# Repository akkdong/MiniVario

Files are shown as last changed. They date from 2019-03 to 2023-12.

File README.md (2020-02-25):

# MiniVario
ESP32+BARO+GPS+E-INK

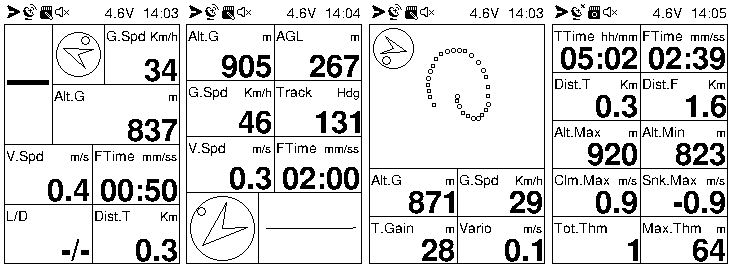
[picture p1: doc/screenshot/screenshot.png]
Device Screenshots


<br>
<br>
<center>
  <p>
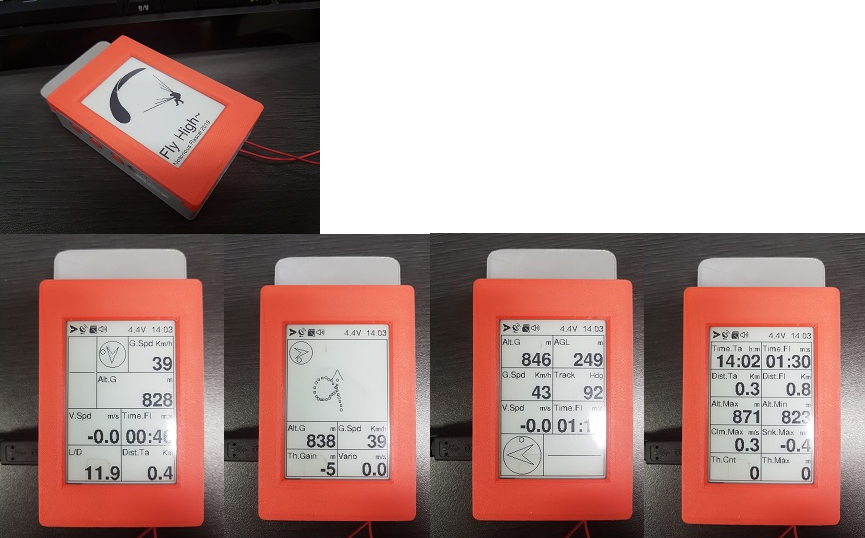
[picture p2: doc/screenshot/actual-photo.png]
    
  </p>
  <p>
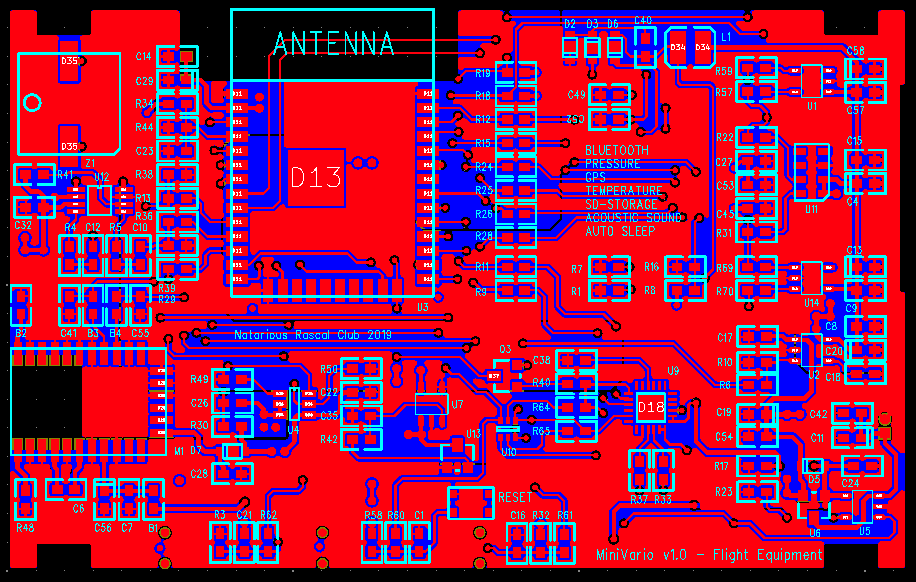
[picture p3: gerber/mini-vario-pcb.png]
    
  </p>
</center>

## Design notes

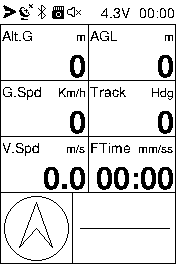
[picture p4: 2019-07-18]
doc/screenshot/screen02.bmp

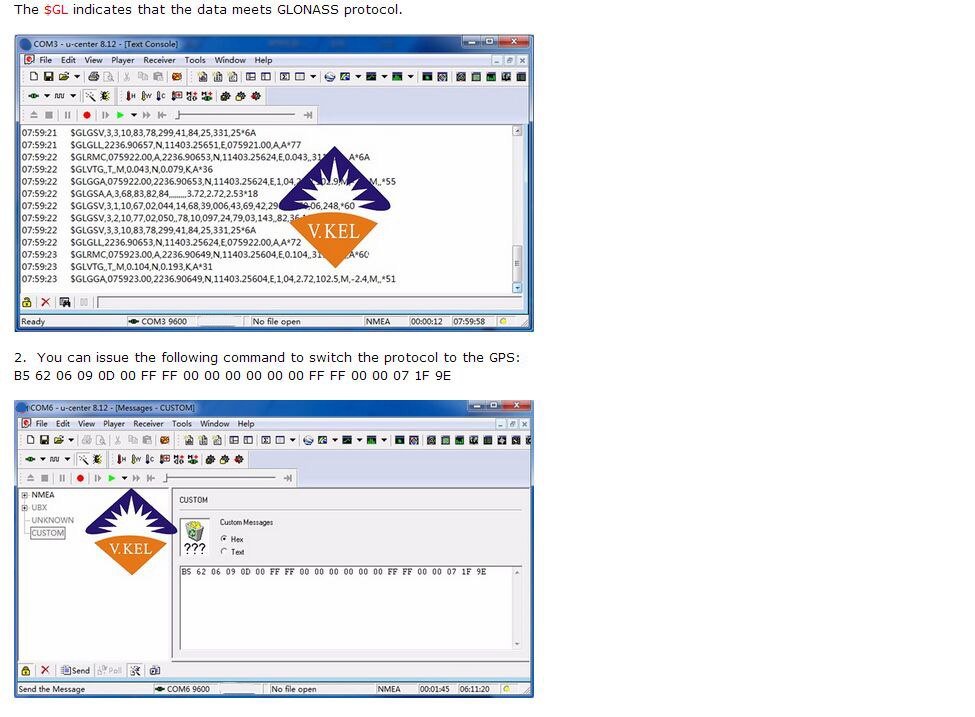
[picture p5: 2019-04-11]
doc/gps-alternate/6 GPS and GLONASS Switching.jpg

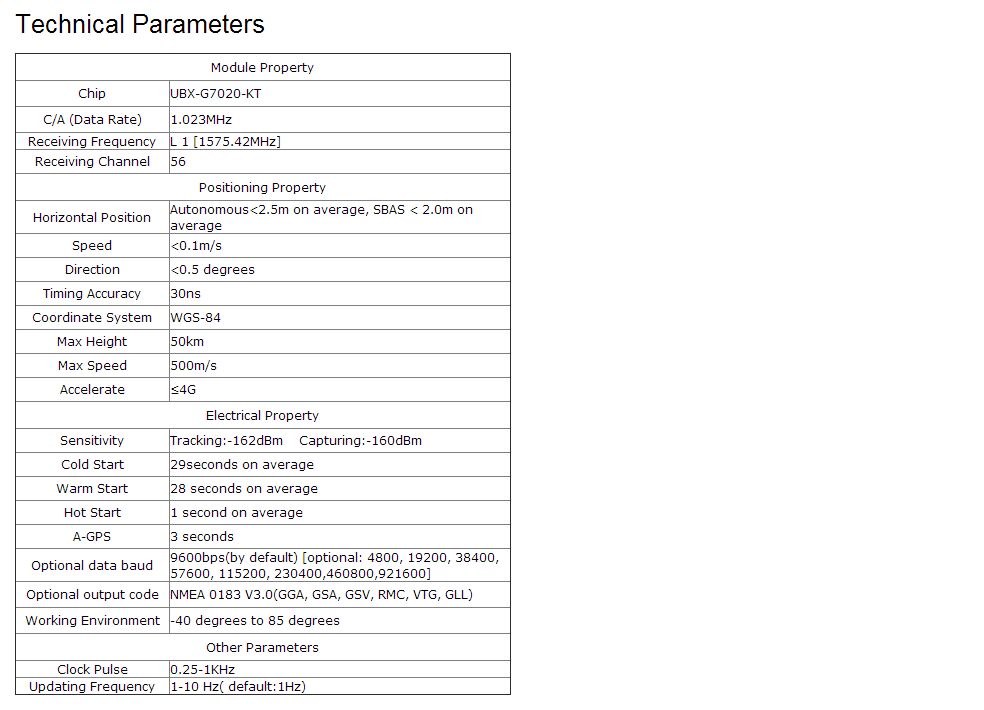
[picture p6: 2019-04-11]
doc/gps-alternate/1 Technical Parameters.jpg

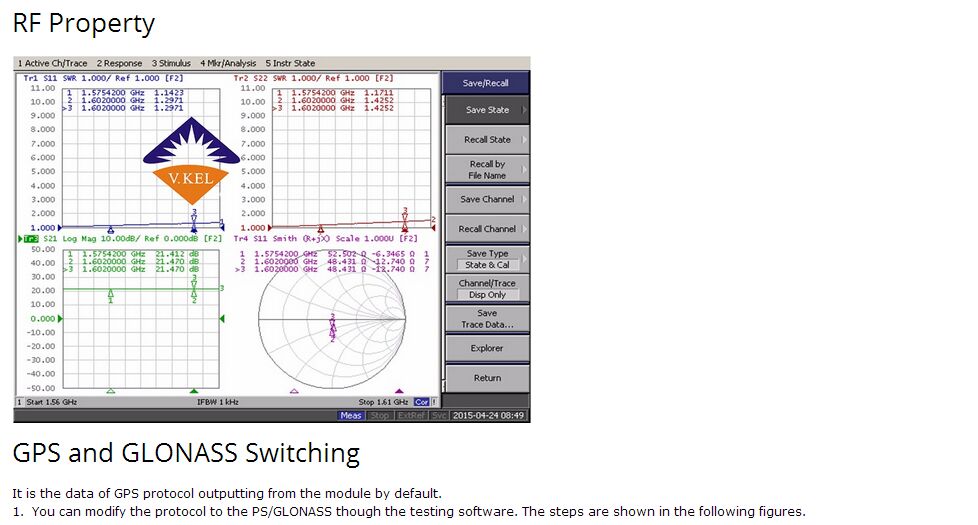
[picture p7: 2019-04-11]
doc/gps-alternate/4 RF Property.jpg

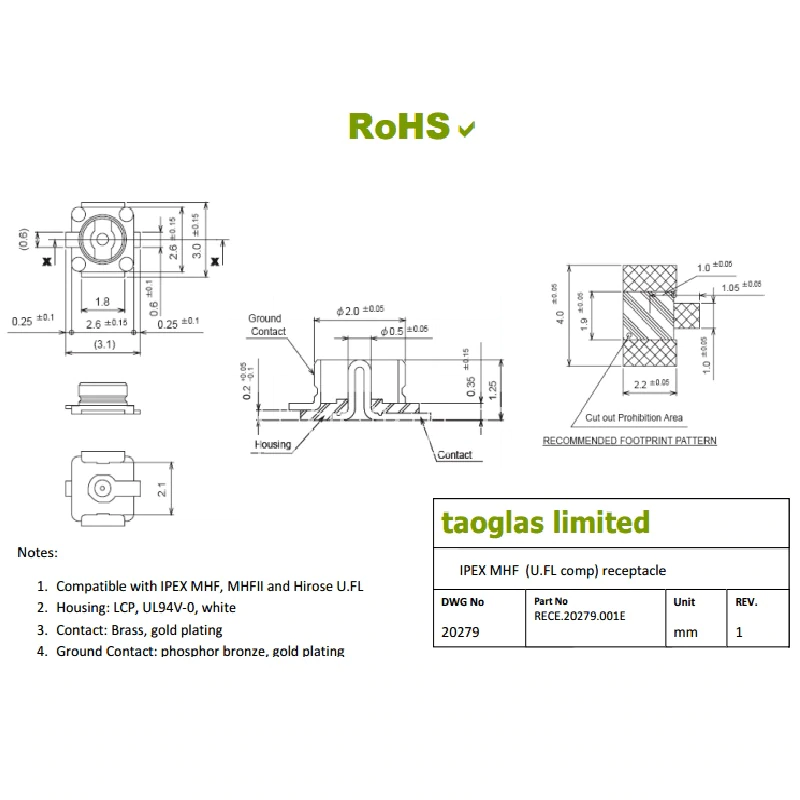
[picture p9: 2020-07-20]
doc/IPEX-IPX-connetor.webp

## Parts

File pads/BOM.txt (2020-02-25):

Item	Qty	Reference	Part Name	Manufacturer	Description
1	1	U14	24CW128X		
2	1	U6	AO3401A		
3	1	Q3	BC817-16LT1	MOTOROLA	GENERAL PURPOSE NPN SILICON TRANSISTOR
4	2	L4-5	BEAD		
5	1	B2	BEAD-0603(1608),1.8nH		
6	2	B3-4	BEAD-0603(1608),47nH		
7	1	B1	BEAD-0603(1608),ferrite 1K, 1MHz		
8	1	Z1	BUZZER		
9	1	C23	C-N-0603(1608),0.01uF		
10	16	C1-3 C7-9 C14-15 C21 C25 C27 C37 C40 C42 C54 C57	C-N-0603(1608),0.1uF		
11	1	C16	C-N-0603(1608),0.1uF(NC)		
12	1	C26	C-N-0603(1608),1000pF		
13	18	C10 C12 C17 C22 C28 C32-33 C35 C43-52	C-N-0603(1608),1uF		
14	2	C31 C39	C-N-0603(1608),220pF		
15	3	C6 C41 C55	C-N-0603(1608),22pF		
16	1	C24	C-N-0603(1608),4.7uF		
17	1	C38	C-N-0603(1608),4.7uF (NC)		
18	1	C53	C-N-0603(1608),47uF		
19	1	C18	C-N-0603(1608),N/C		
20	1	C59	C-N-0603(1608),SHORT		
21	12	C4-5 C11 C13 C19-20 C29-30 C34 C36 C56 C58	C-P-0805(2012),10uF		
22	1	L1	COIL,???		
23	1	U9	CP2104		
24	5	D2-3 D5-7	D-1206(3216),S1M		
25	1	J3	EINK-WARESHARE		
26	1	U3	ESP-WROOM32		
27	1	U4	FDC6326L		
28	1	M1	GPS_M20050-1		
29	2	D1 D4	LED		
30	1	U13	MAX809		
31	1	U1	MCP9800		
32	1	U5	MCP73831		
33	1	J2	MICRO-SD		
34	1	U11	MS5611-01BA		
35	1	U12	PAM8304		
36	2	R8 R16	R-0603(1608),0K		
37	10	R9 R11-12 R15 R24-26 R28 R33 R37	R-0603(1608),0R		
38	5	R30 R40 R48 R64-65	R-0603(1608),100K		
39	14	R6 R21-22 R27 R29 R31 R35 R45-47 R57 R59 R69-70	R-0603(1608),100R		
40	18	R1 R3 R10 R14 R17-19 R32 R38-39 R41 R50-54 R56 R58	R-0603(1608),10K		
41	5	R2 R20 R49 R66-67	R-0603(1608),1K		
42	2	R42 R44	R-0603(1608),1M		
43	1	R23	R-0603(1608),2K		
44	1	R7	R-0603(1608),3R/0.47R		
45	3	R13 R36 R43	R-0603(1608),4.7K		
46	4	R60-63	R-0603(1608),470R		
47	2	R4-5	R-0603(1608),50K		
48	1	R34	R-0603(1608),560K		
49	1	R55	R-0603(1608),N/C		
50	1	Q1	SI1308EDL		
51	1	J5	SIP_02		
52	4	SW1 SW3-5	SW-SPST-ITS-1164		
53	1	U2	TC1017-3V3		
54	1	U7	TPS78233		
55	1	U10	UMH3N		
56	1	J1	USB_TYPEB_MINI

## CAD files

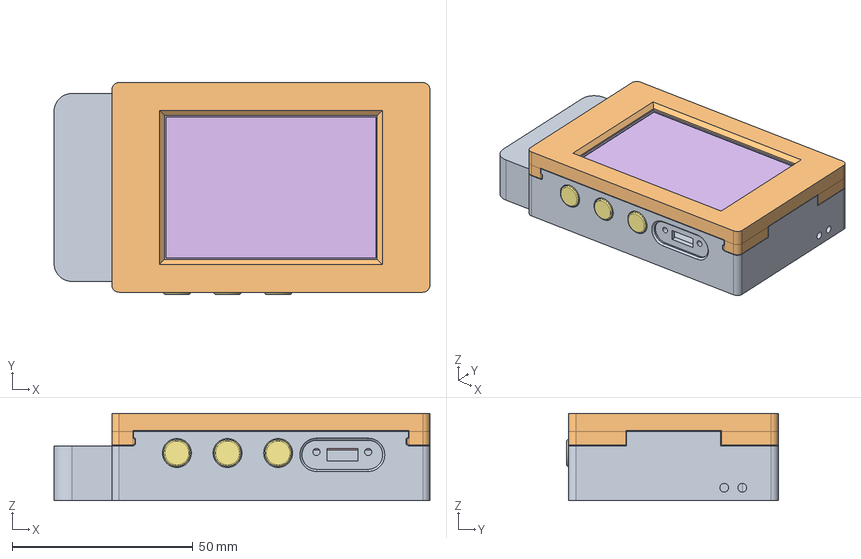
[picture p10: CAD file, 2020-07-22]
model/Case-Alt-RoundBtn.FCStd
104.0 x 58.6 x 24.2 mm
Case-Lower
Case-Cover
LCD-Holder-L
LCD-Holder-R
PCB-Body
LCD-Body
Buttons

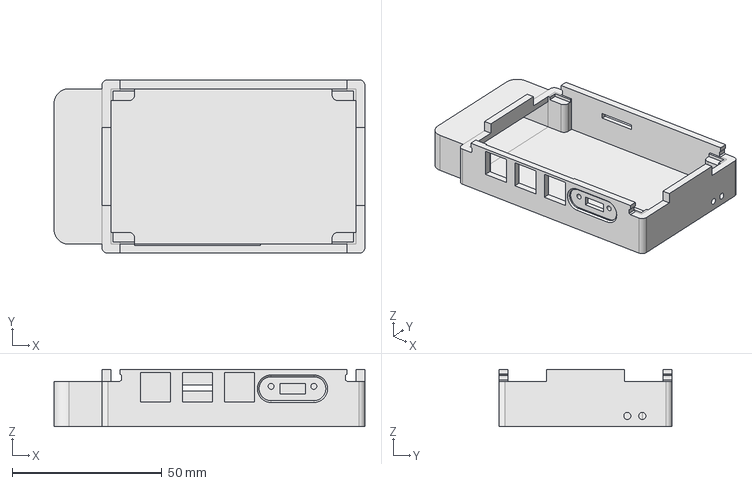
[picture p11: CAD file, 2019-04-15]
model/Case-Alt.FCStd
104.0 x 58.0 x 19.2 mm

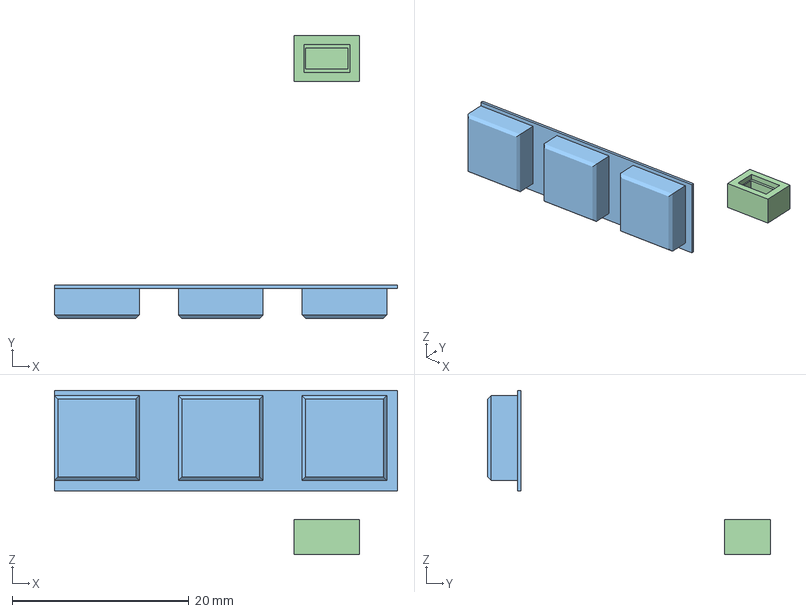
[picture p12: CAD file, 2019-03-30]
model/Case.FCStd
38.8 x 32.0 x 18.6 mm
Buttons
MS5611-Cover
Buttons (Meshed)
MS5611-Cover (Meshed)

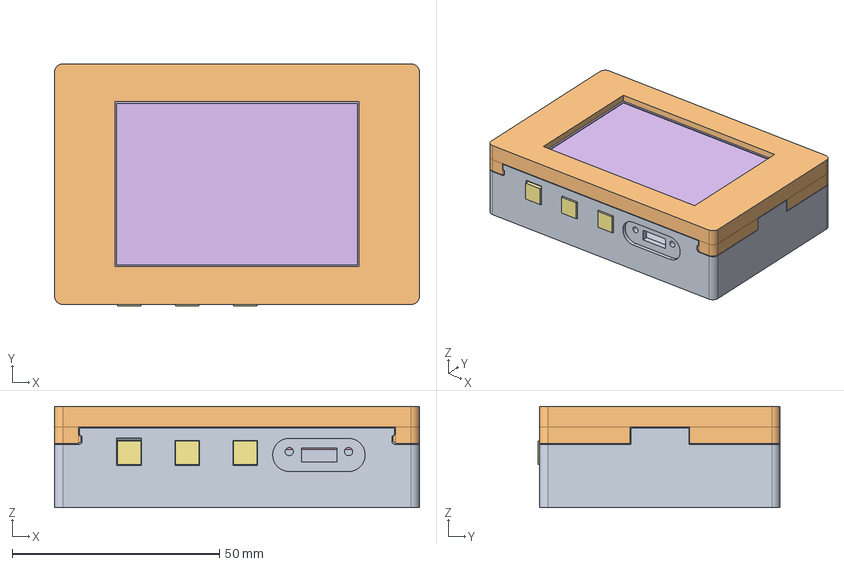
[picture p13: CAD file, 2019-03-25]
model/Case-Small Button.FCStd
88.0 x 58.4 x 24.4 mm
Case-Lower
Case-Cover
LCD-Holder-L
LCD-Holder-R
PCB-Body
LCD-Body
Buttons

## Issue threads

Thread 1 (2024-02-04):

Failed to start after welding

mspudi, 2024-02-04:
1：MiniVario_Rev2.pcb   Failed to start after welding

2：MiniVario_Rev2.pdf / MiniVario_Full.pdf  There is no difference between the two

3：src-platformio   /  Arduino IDE  master/src/    Burn test after compilation

Make sure there is no problem with the circuit

akkdong, 2024-02-22:
1. Hm...
- Actually GPS has problem but it's not affect to boot up.
- Please check one by one:  Power, USB(2serial), ...

2. Power input of GPS module is changed.
- Anyway GPS works well. but it cann't find satellite
- External ANTENA is needed. : I will show how to fix it.

3. recommend src-platformio
- use proper EPD: refer USE_GOOD_DISPLAY  macro in platformio.ini

--> There is no problem to start but some H/W fix is needed.

mspudi, 2024-10-08:
[2024-09-30 13:32:45.227]# RECV ASCII>
Start MiniVario...
[2024-09-30 13:32:45.354]# RECV ASCII>
Initializing SD card...
E (336) sdmmc_io: sdmmc_io_reset: unexpected return: 0x108
E (337) vfs_fat_sdmmc: sdmmc_card_init failed (0x108).
[   358][E][SD_MMC.cpp:148] begin(): Failed to initialize the card (0x108). Make sure SD card lines have pull-up resistors in place.
SD Card Mount Failed
Failed to initialize SD Card.

[2024-09-30 13:32:45.650]# RECV ASCII>
DeviceDefault.enableBT = 0
DeviceDefault.enableSound = 0
DeviceDefault.enableSimulation = 0
DeviceDefault.enableNmeaLogging = 0
DeviceDefault.btName = MiniVario
DeviceDefault.wifiSSID = MiniVario
DeviceDefault.wifiPassword = 123456789
VolumeSettings.vario = 0
VolumeSettings.effect = 100
VolumeSettings.autoTurnOn = 1
VarioSettings.sinkThreshold = -3.000000
VarioSettings.climbThreshold = 0.200000
VarioSettings.sensitivity = 0.120000
VarioSettings.sentence = 2
VarioSettings.altitudeRef1 = 0.000000
VarioSetting

[2024-09-30 13:32:45.742]# RECV ASCII>
s.altitudeRef2 = 0.000000
VarioSettings.altitudeRef3 = 0.000000
VarioSettings.dampingFactor = 0.050000
KalmanParameter.varZMeas = 400.000000
KalmanParameter.varZAccel = 50000.000000
KalmanParameter.varAccelBias = 1.000000
GliderInfo.type = 1
GliderInfo.manufacture = Ozone
GliderInfo.model = Zeno
IGCLogger.enable = 1
IGCLogger.takeoffSpeed = 6
IGCLogger.landingSpeed = 2
IGCLogger.landingTimeout = 10000
IGCLogger.loggingInterval = 1000
IGCLogger.pilot = akkdong
IGCLogger.timezone = 9.000000

[2024-09-30 13:32:46.784]# RECV ASCII>
E (3978) task_wdt: Task watchdog got triggered. The following tasks did not reset the watchdog in time:
E (3978) task_wdt:  - loopTask (CPU 1)
E (3978) task_wdt: Tasks currently running:
E (3978) task_wdt: CPU 0: IDLE0
E (3978) task_wdt: CPU 1: IDLE1
E (3978) task_wdt: Aborting.

abort() was called at PC 0x400f5160 on core 0
Backtrace: 0x40083fe1:0x3ffbf17c |<-CORRUPTED
ELF file SHA256: 9320ff9e2883cf93
[2024-09-30 13:32:47.000]# RECV ASCII>
Rebooting...

mspudi, 2024-10-08:
I use an external module for GPS, as long as it can decode NMEA, that's enough。The system keeps restarting after power on, please modify it       void resetDevice()
{
	//
	display.showPopup(NULL);

	//
	btMan.stopLogging();
	btMan.end();

	// close logging-file
	logger.end(nmeaParser.getDateTime());

	// turn-off peripherals
	setPinState(&powerPins[0], PIN_STATE_INACTIVE);
	setPinState(&powerPins[1], PIN_STATE_INACTIVE);
	delay(1000); // delay will trigger Task watchdog!

	// or manually reset
	ESP.restart();
}

akkdong, 2024-10-13:
The current problem is caused by watchdog timeout. The watchdog count should be reset periodically. The watchdog resets itself periodically in the main loop and in the kalman-vario task. For some reason, the loop does not seem to work properly. You may be able to determine why the loop stops working by disabling the watchdog. Try commenting out all lines starting with "TaskWatchodog::" in main.cpp and KalmanVario.cpp, or changing the value of the TASK_TIMEOUT_S macro to a larger value. TASK_TIMEOUT_S is the watchdog timeout period, which is currently set to 1 second.

mspudi, 2024-10-17:
I'm ready to use it https://github.com/moononournation/Arduino_GFX Can you explain the logic and method of replacing EPaper with ILI9341? Thank you. Currently, the MiniVario motherboard has been used to test the Arduino FX examples    ILI9341   Display successful.
 platformio.ini
    adafruit/Adafruit GFX Library @ ~1.11.5
    adafruit/Adafruit BusIO@^1.16.1
    moononournation/GFX Library for Arduino@^1.4.7

mspudi, 2024-11-28:
The settings in Device Settings fail to be saved after modification.
The Firmware Update is ineffective.
The download of Track Logs is not working.
Are the above several functions not completed?

akkdong, 2024-11-30:
1. DeviceContext::load() and DeviceContext::save() unsupported
Now device-context is loaded from "config.json" file: main.cpp line 1032
Actually it is read-only. You must update "config.json" in manually
2. Firmware Update
It is not tested!!
3. Track Log download
Of cause It is working. But it's tricky to use.
Web service use WebServer class which is implemented a long time ago. However WebServer supports only on connection at a time, so its functionality is limited. There is new method which is uses Capital Portal. If you look at Cube-M3, There is something you can refer to. (https://github.com/akkdong/Cube/tree/main/M3/disp) Thre is a plan to renew MiniVario, But thre is not enough time. Sorry!

mspudi, 2024-12-12:
Thank you for your answer. The above functions have been basically fixed, but further testing is still needed. Could you please tell me why there is no sound even when the sound is turned on, whether in flight mode or normal mode?

akkdong, 2024-12-13:
There may be several reasons why there is no sound. The best way to find the cause is to upload the sound test firmware and check the signal of each stage (MCU, FILTER, AMP, SPK). You can use the src/test/SineWave firmware, but since it is a previous build environment, it seems that some additional work is needed. Also, you need to check the pin number in advance.
If everything is fine and there is no sound even when you turn on the sound in normal mode, it may not be easy to find the cause. I don't have any ideas yet on how to fix this.

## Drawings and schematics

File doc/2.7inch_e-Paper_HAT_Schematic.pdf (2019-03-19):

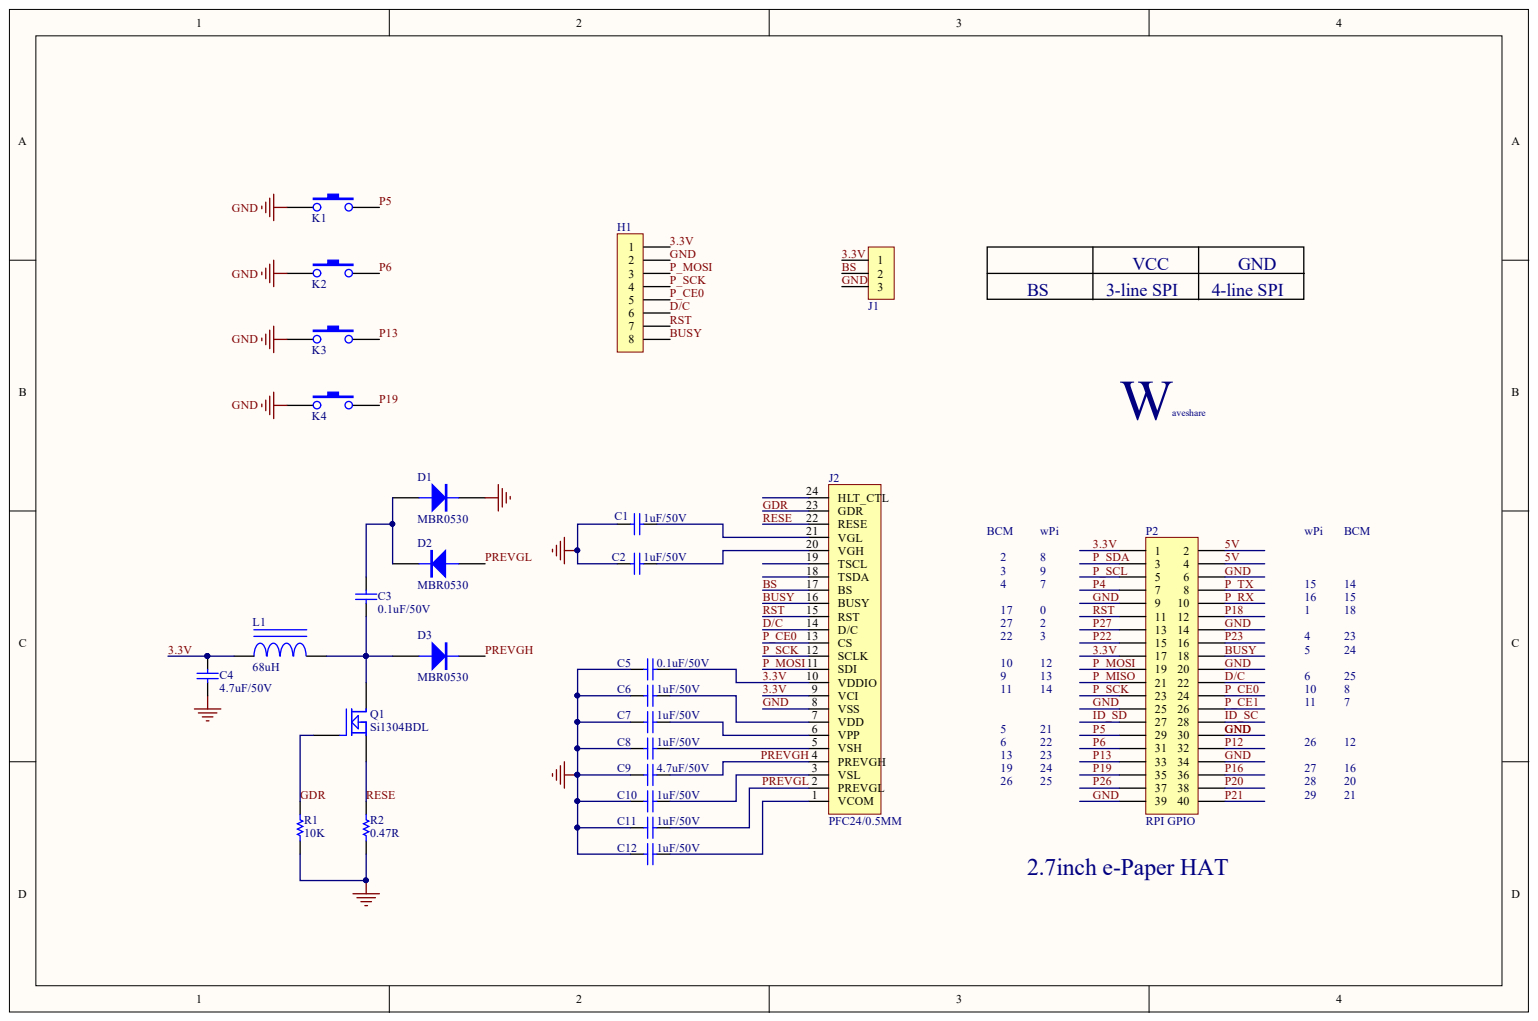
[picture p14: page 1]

PRE V G L | 2

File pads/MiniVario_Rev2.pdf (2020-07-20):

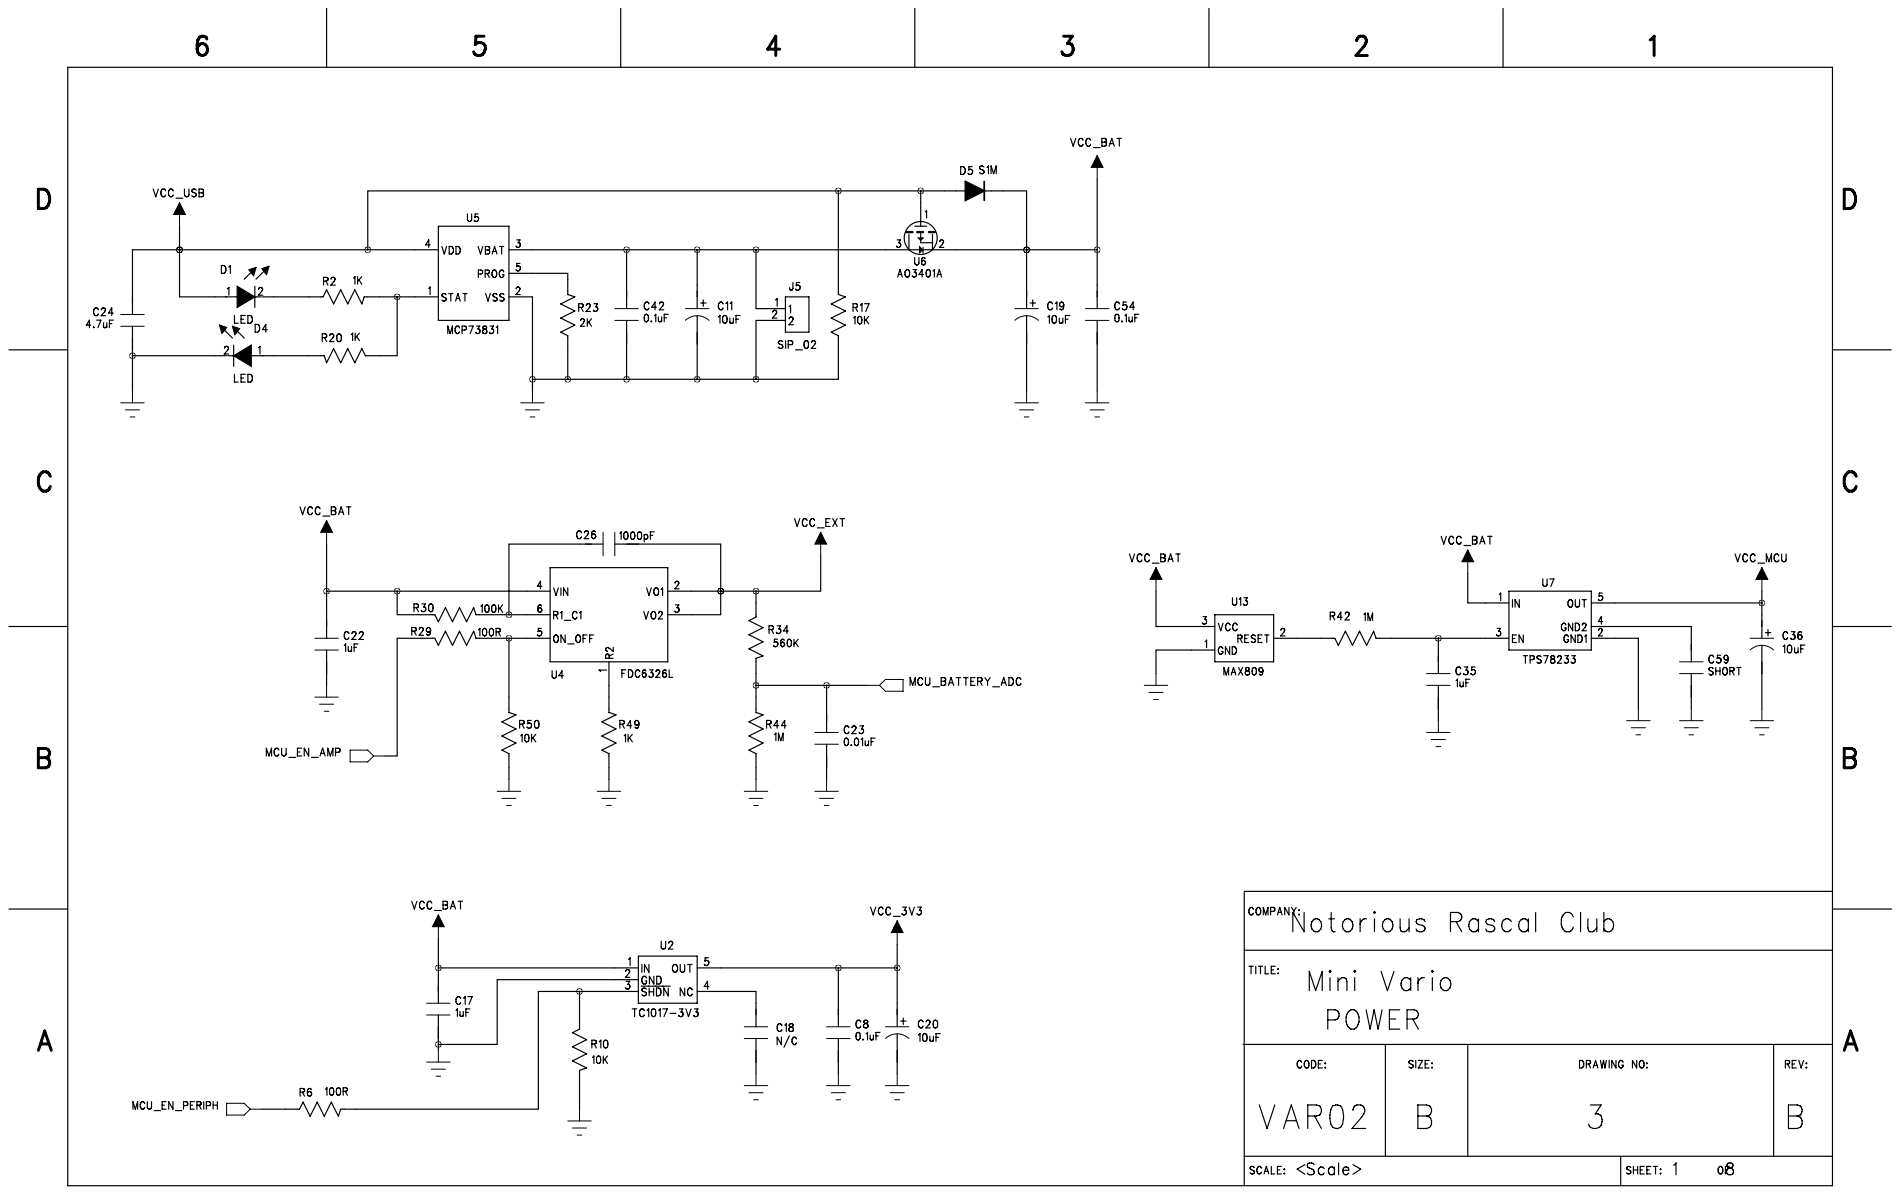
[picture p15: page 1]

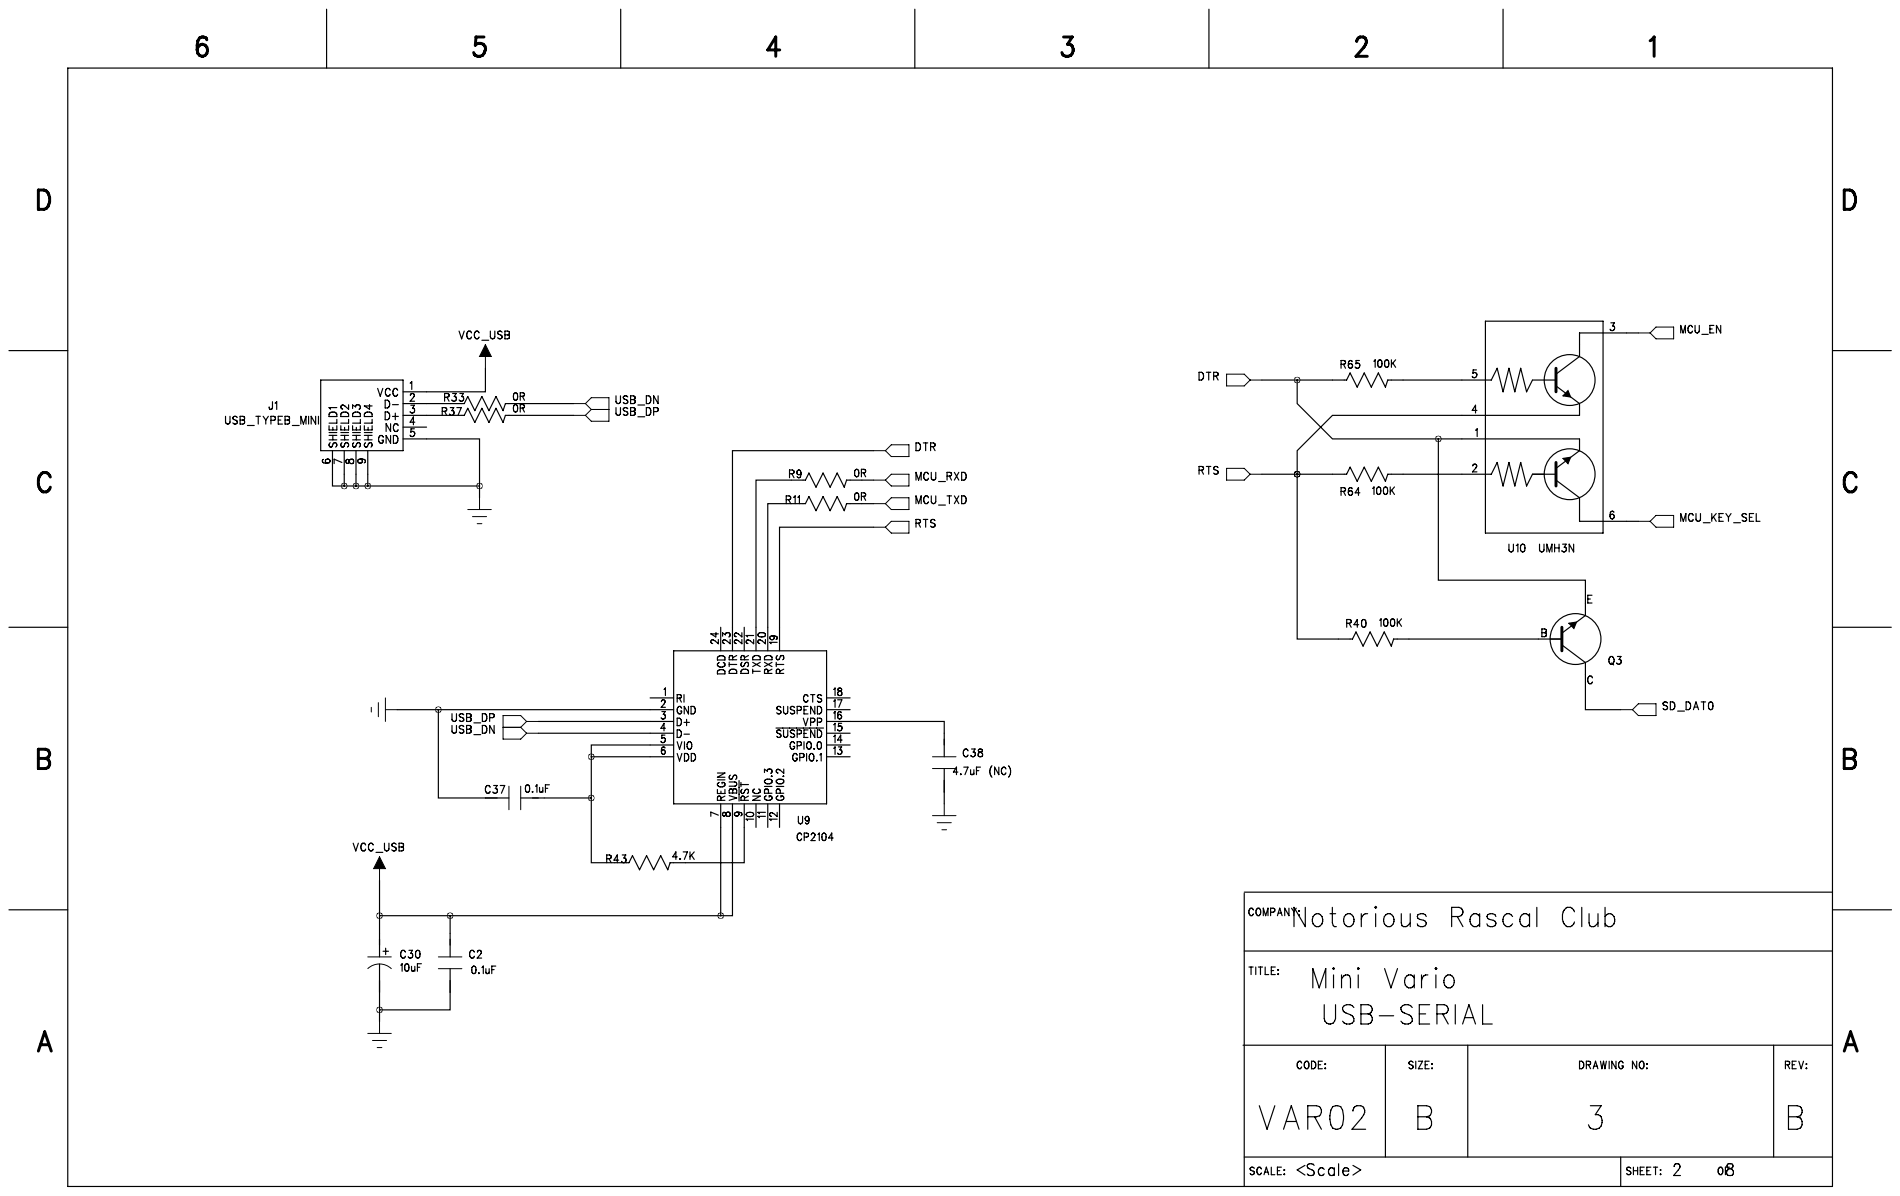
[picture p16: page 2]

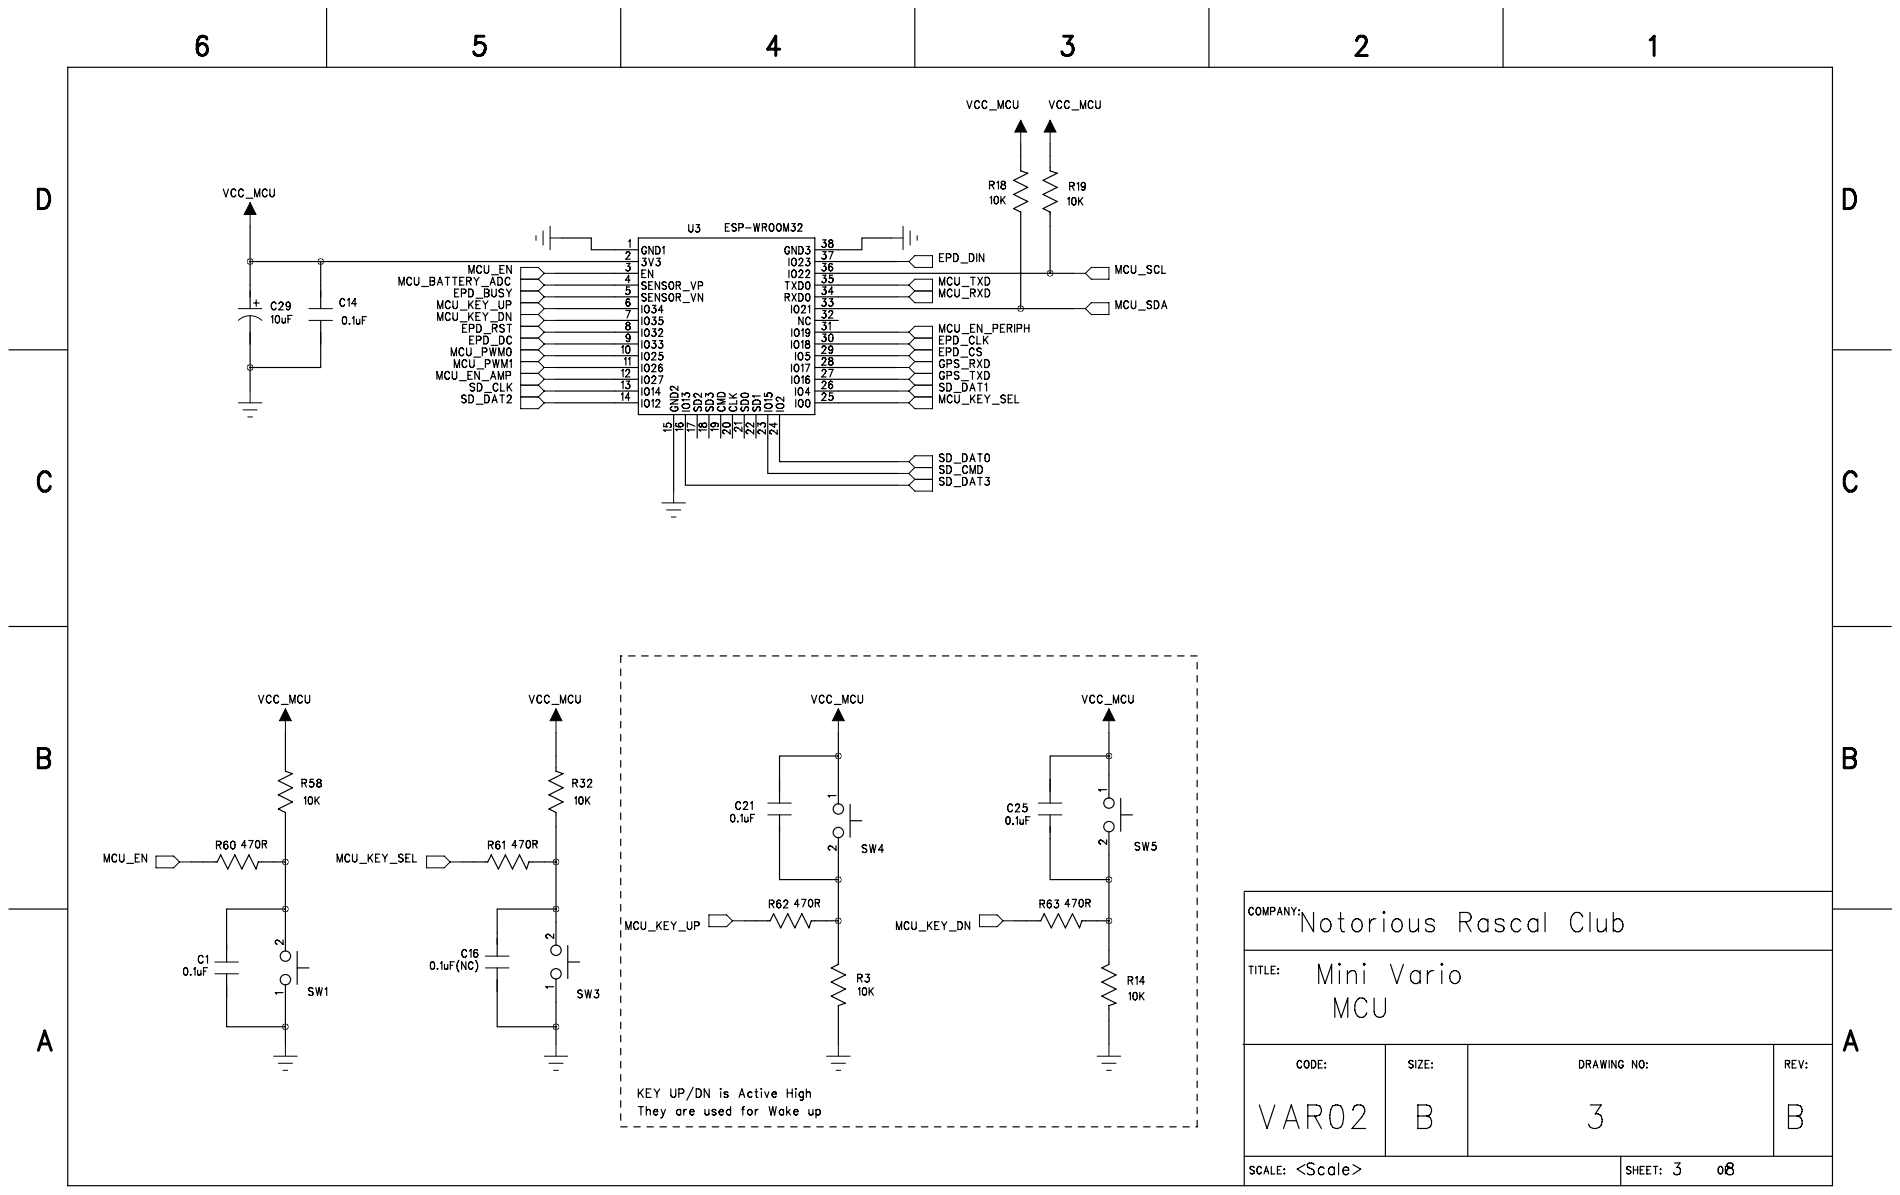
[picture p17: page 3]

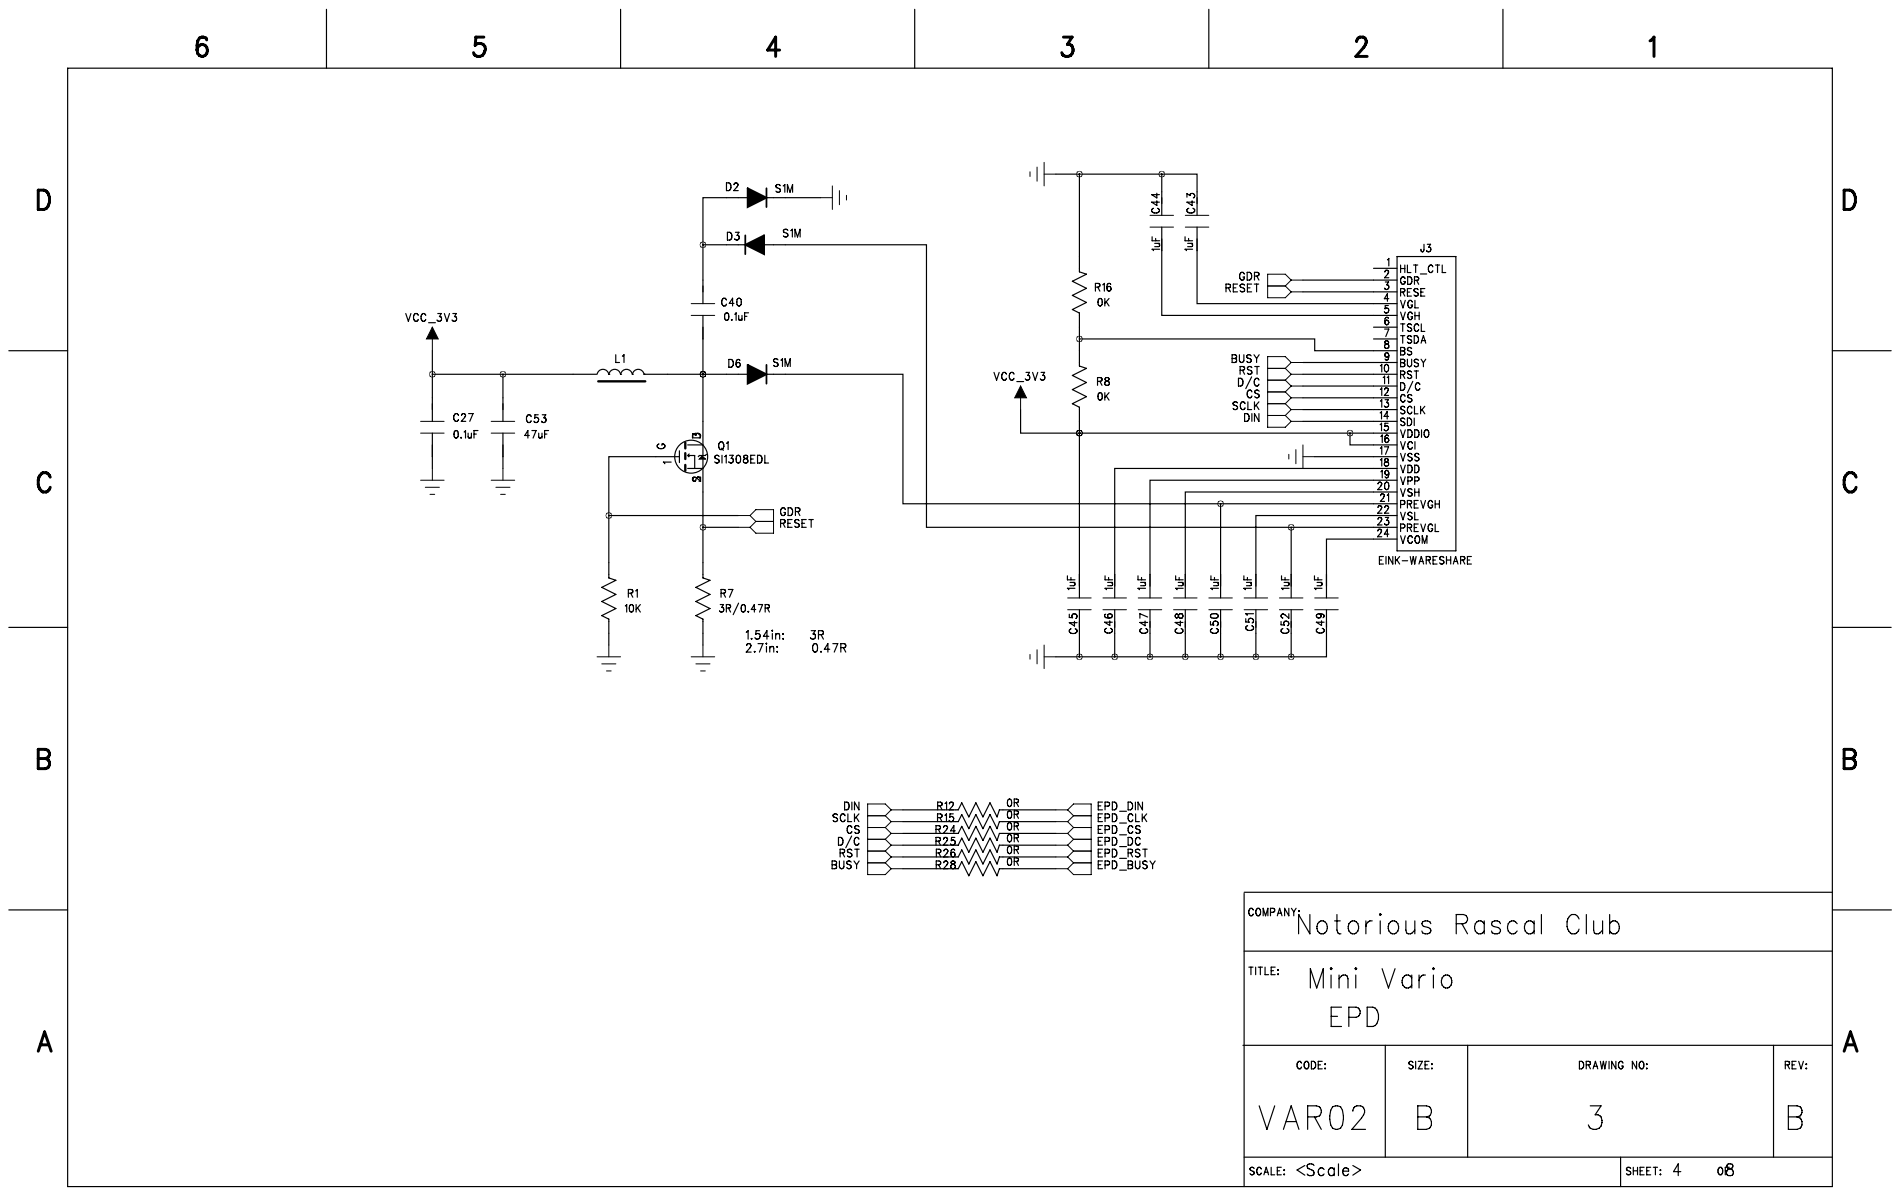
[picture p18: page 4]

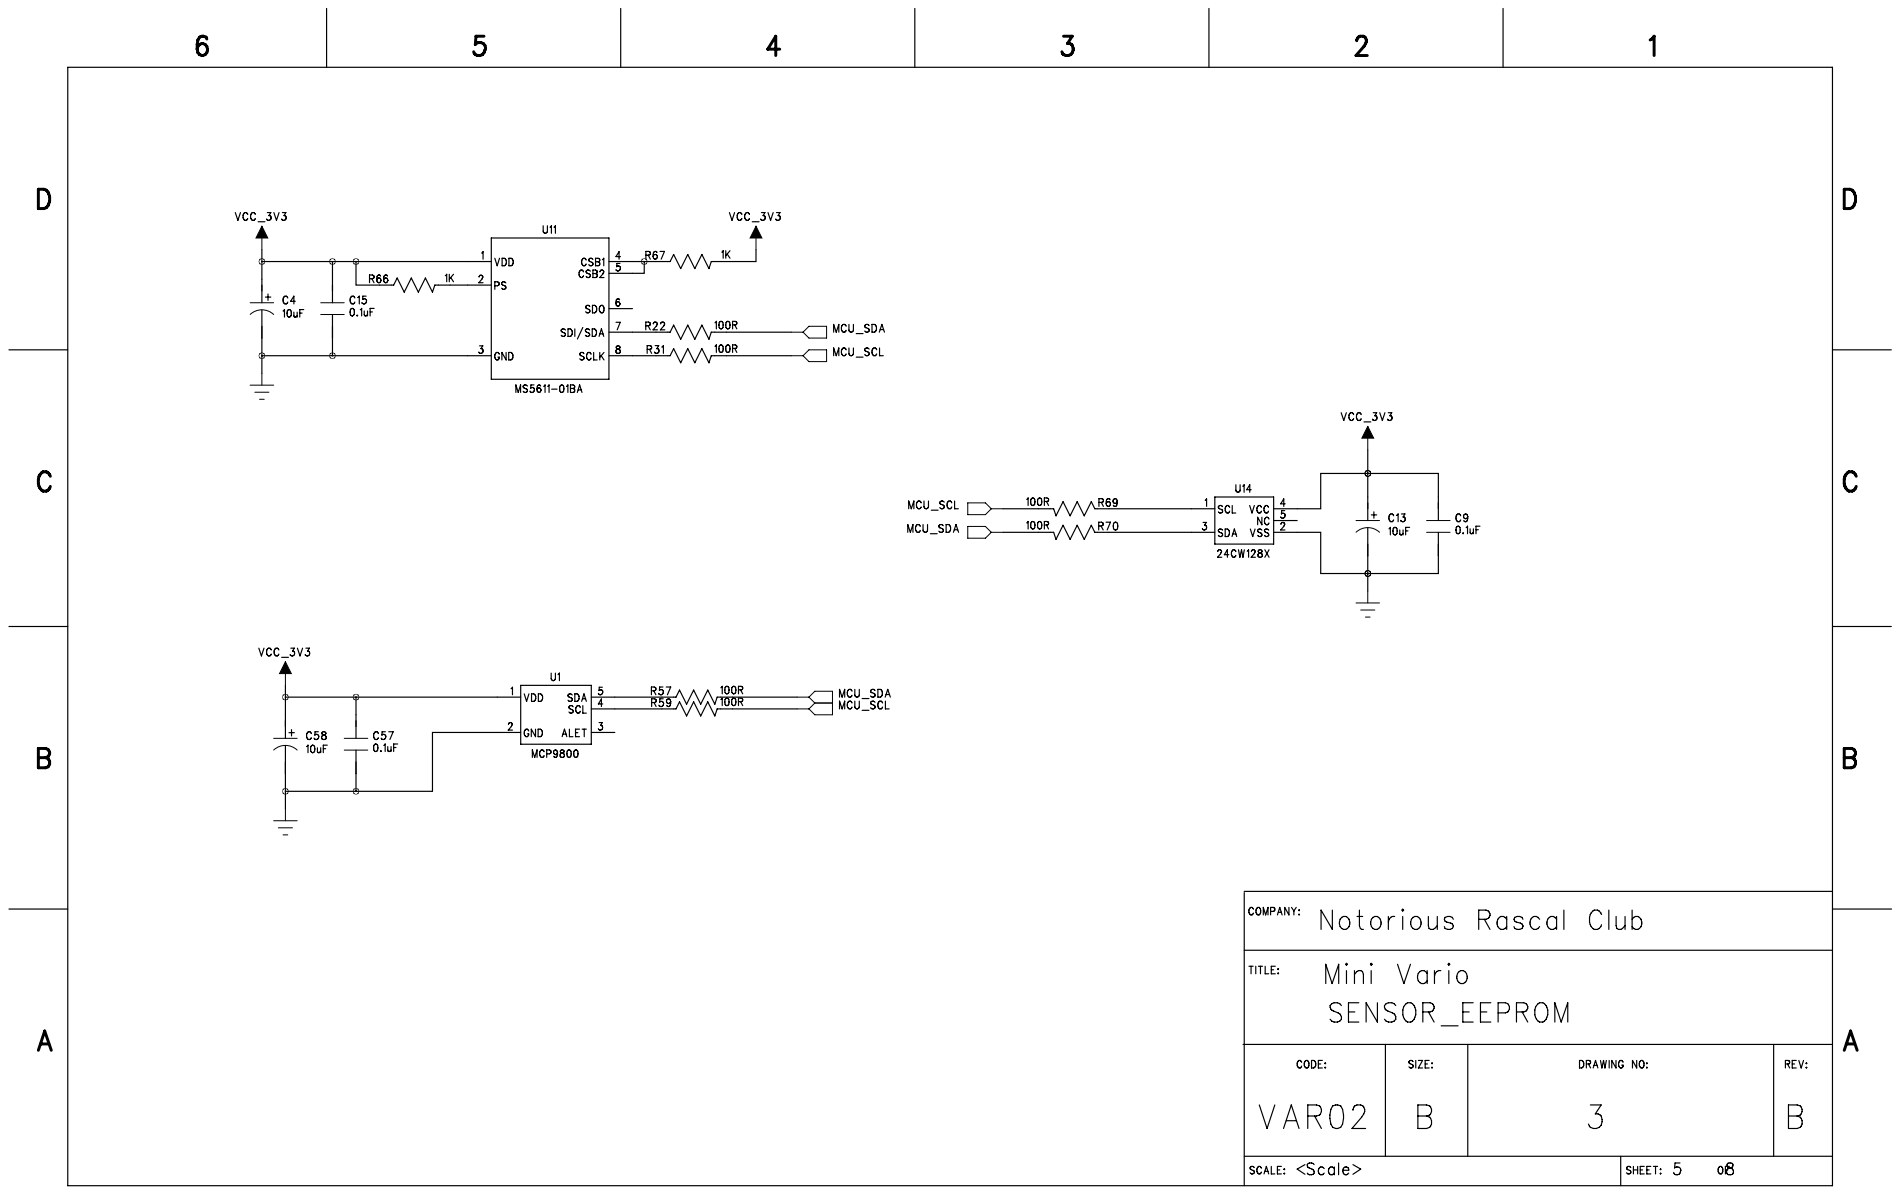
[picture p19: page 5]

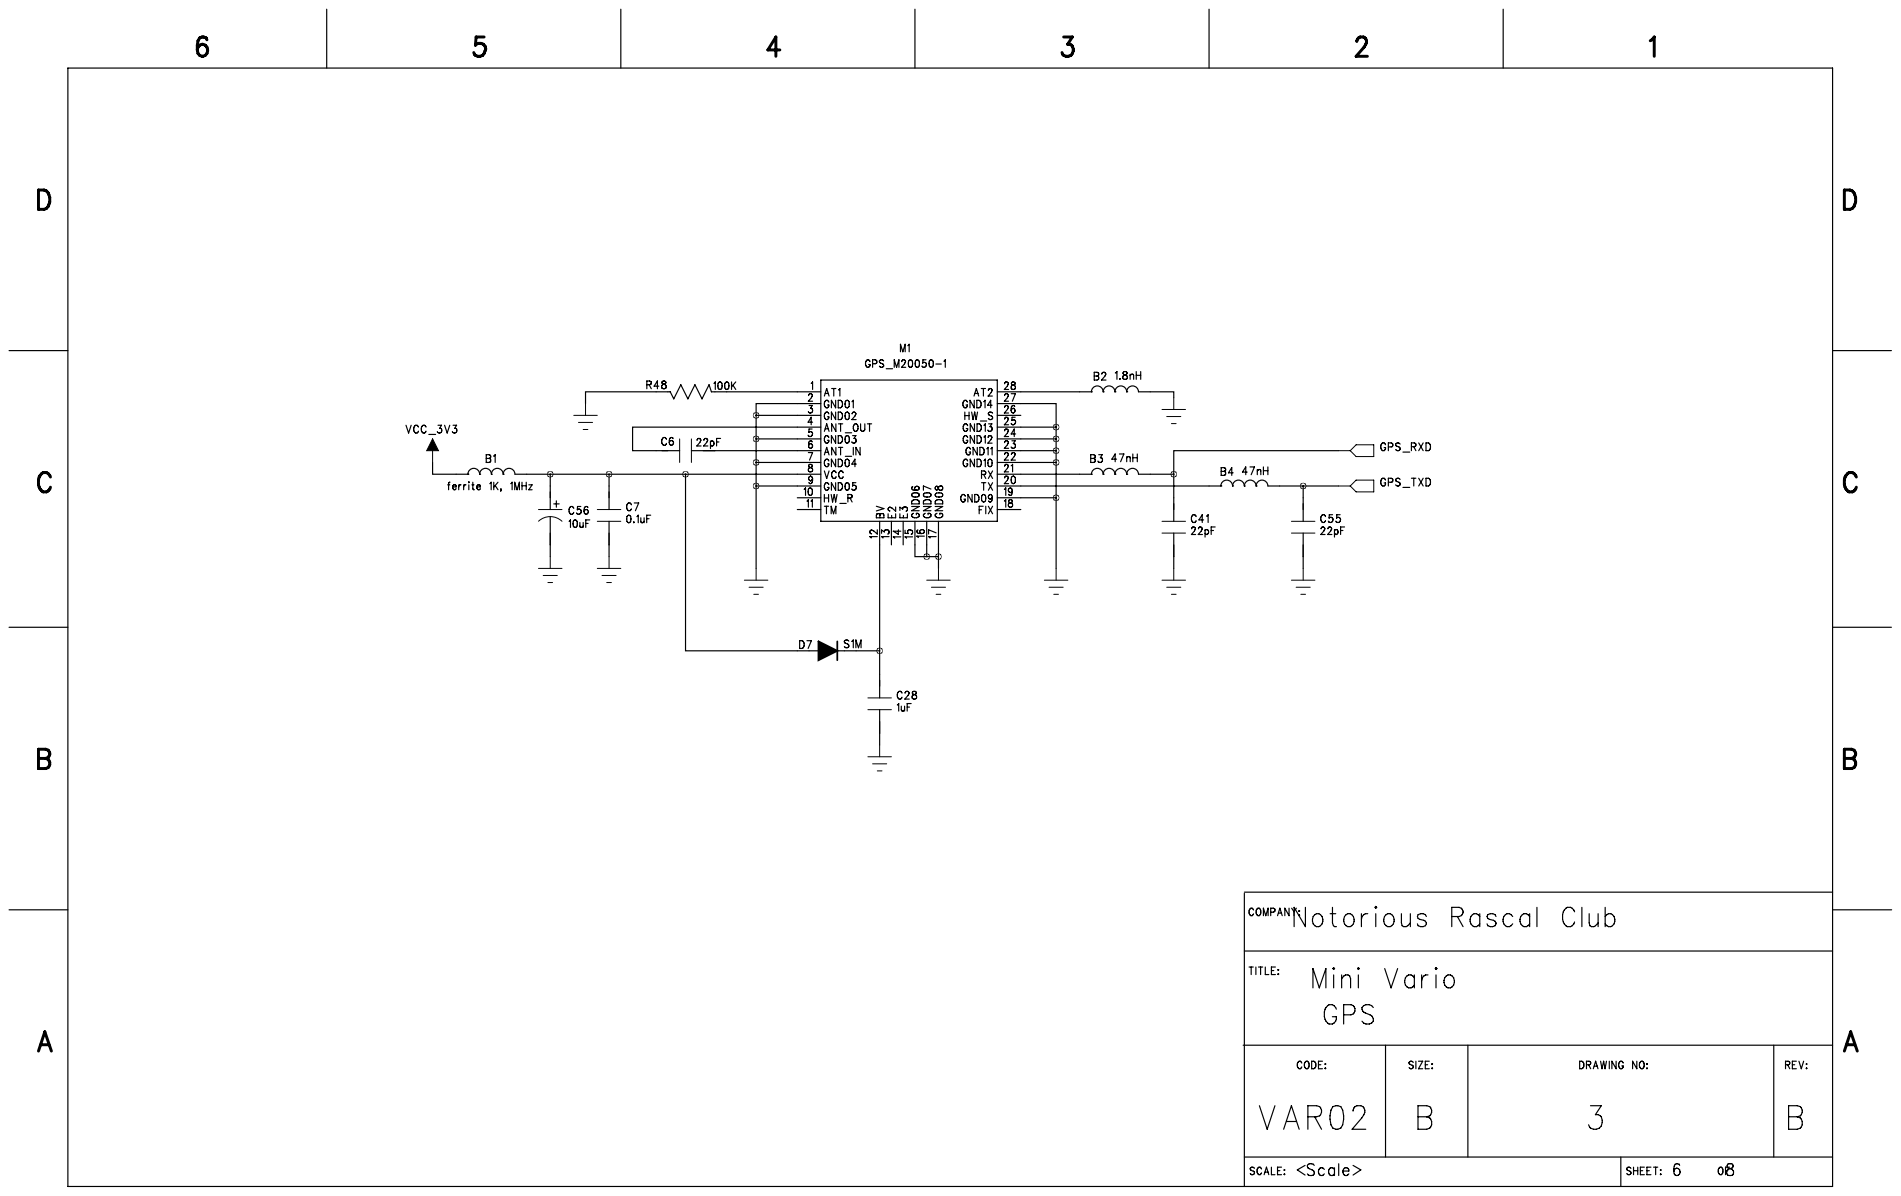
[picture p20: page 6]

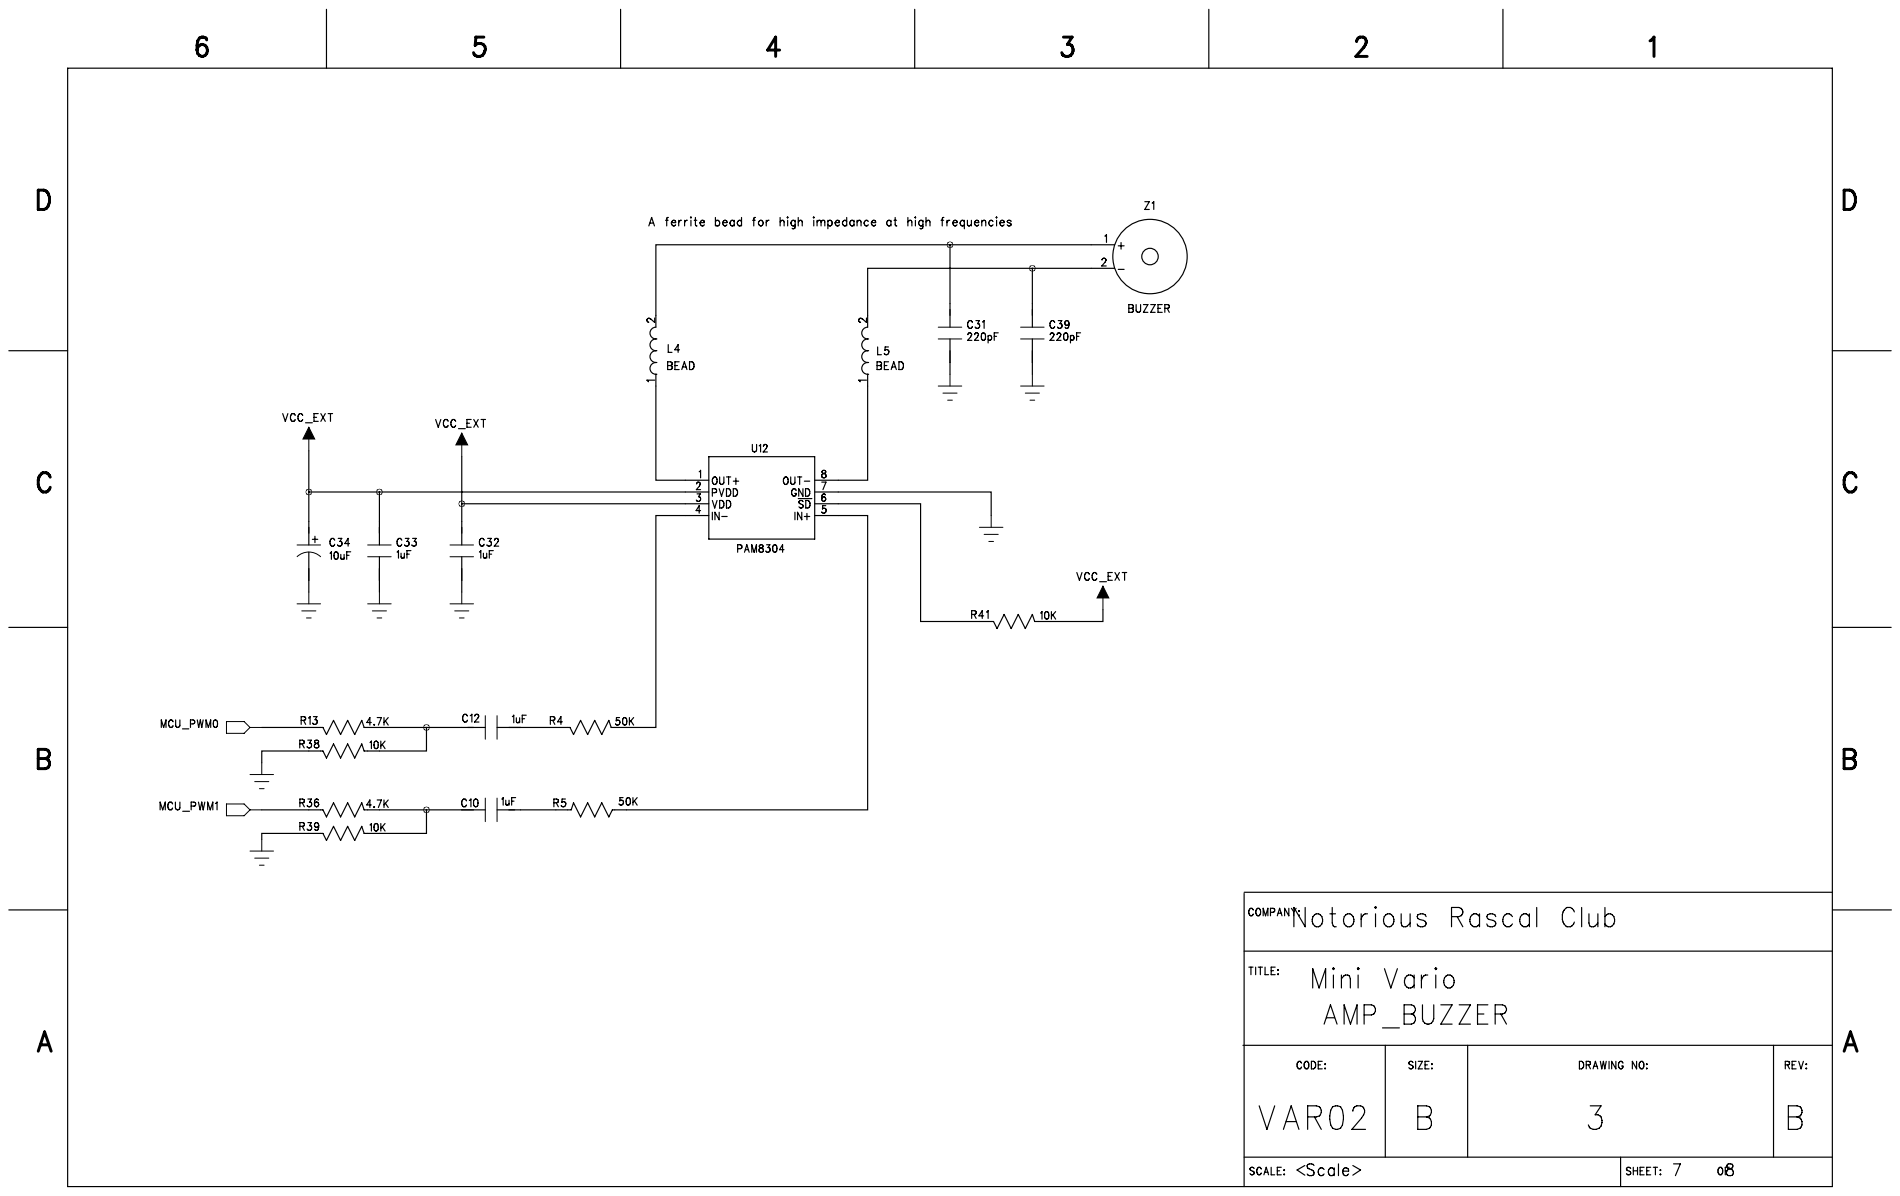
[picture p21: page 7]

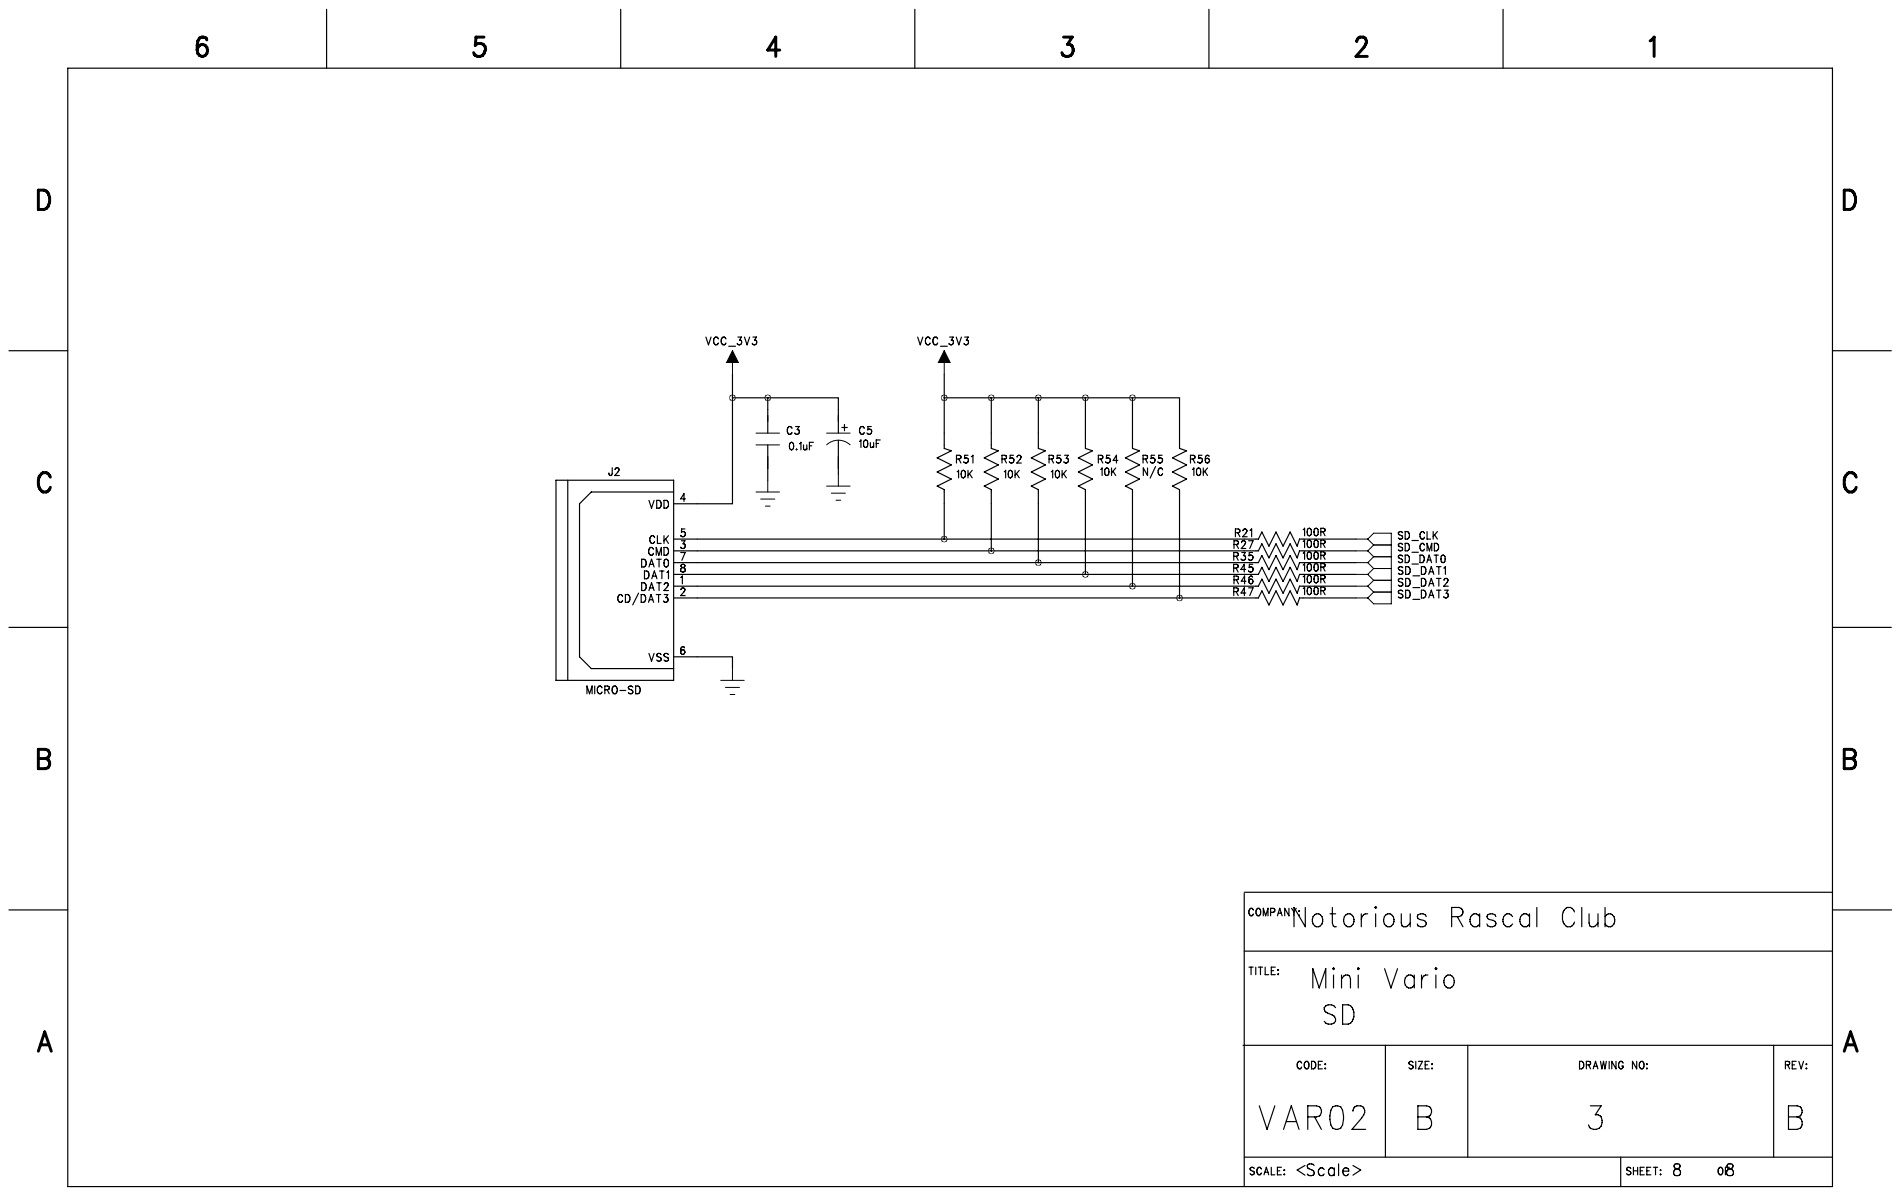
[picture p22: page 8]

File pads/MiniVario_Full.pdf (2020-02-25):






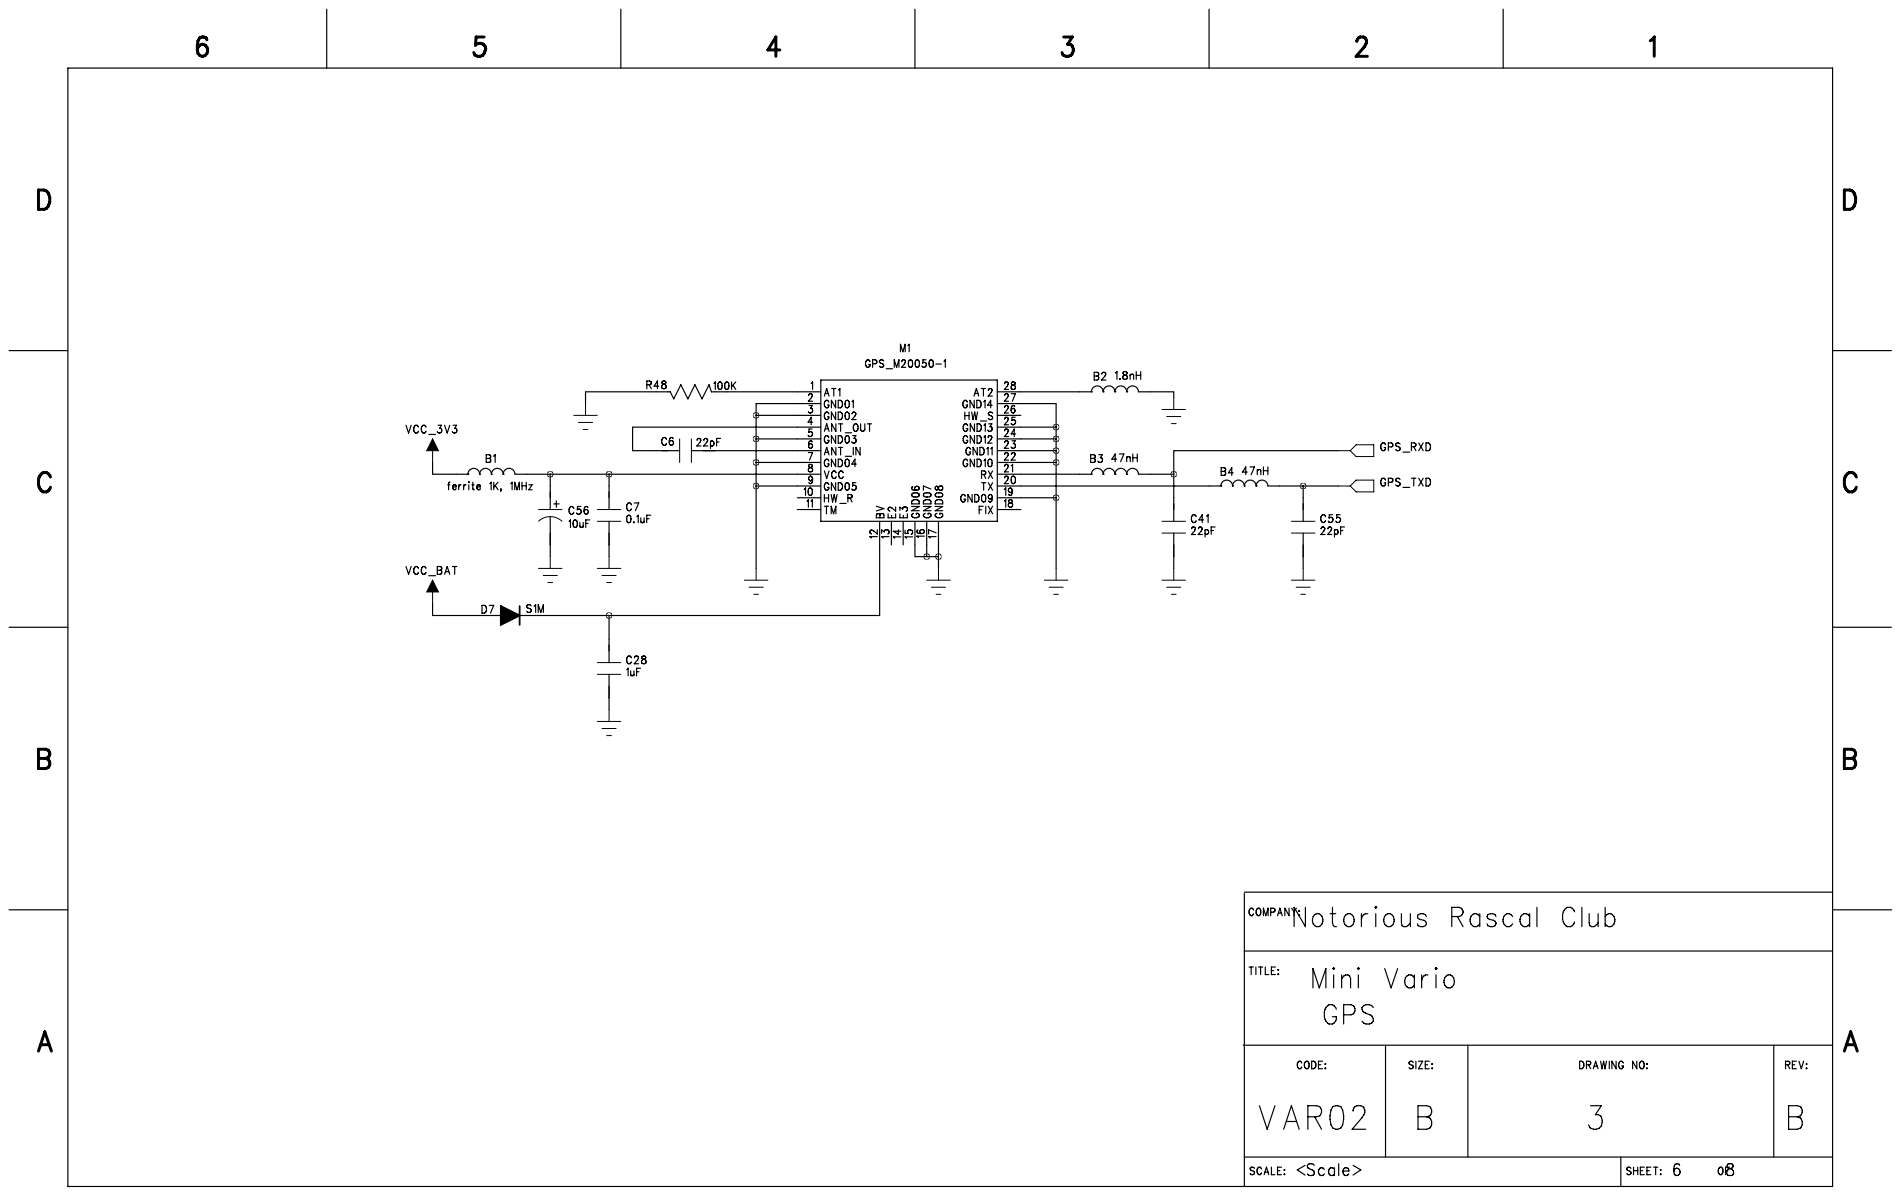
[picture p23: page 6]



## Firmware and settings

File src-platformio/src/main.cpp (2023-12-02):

// main.ino
//

#include <Arduino.h>
#include <SPI.h>
#include <Wire.h>
#include <SD.h>
#include <WiFi.h>
#include <WiFiServer.h>
#include <WebServer.h>
#include <DNSServer.h>
#include <HTTPClient.h>
#include <HTTPUpdate.h>
#include <EEPROM.h>
#include <Ticker.h>
#include <sys/time.h>

#include "VarioDisplay.h"
#include "BatteryVoltage.h"
#include "Keyboard.h"
#include "DeviceDefines.h"
#include "Beeper.h"
#include "BluetoothSerialEx.h"
#include "NmeaParserEx.h"
#include "VarioSentence.h"
#include "VarioLogger.h"
#include "BluetoothMan.h"
#include "Util.h"
#include "AGL.h"
#include "TaskWatchdog.h"
#include "ScreenManager.h"
#include "FirmwareUpdater.h"
#include "ArduinoJson.h"
#include "WebService.h"

#define USE_KALMAN_VARIO 						(1)

#if USE_KALMAN_VARIO
#include "KalmanVario.h"
#else
#include "KalmanSkyDrop.h"
#endif
#include "VerticalSpeedCalculator.h"


#define WEBSERVER_PORT							(80)
#define HOST_NAME								"mini-vario"

#define DAMPING_FACTOR_DELTA_HEADING			(0.1)
#define THRESHOLD_CIRCLING_HEADING				(6)

#define MAX_GLIDING_COUNT						(10)
#define MIN_GLIDING_COUNT						(0)
#define GLIDING_START_COUNT						(6)
#define GLIDING_EXIT_COUNT						(6)
#define CIRCLING_EXIT_COUNT						(3)

#define TASK_TIMEOUT_S							(1)

#define BOOT_CHECKING_TIMOUT					(1200)


////////////////////////////////////////////////////////////////////////////////////////
//
//

enum _DeviceMode
{
	DEVICE_MODE_UNDEF = 0,
	DEVICE_MODE_WAKEUP,			// (1)
	DEVICE_MODE_VARIO,			// (2)
	DEVICE_MODE_VARIO_AND_GPS,	// (3)
	DEVICE_MODE_PREFERENCE,		// (4)
	DEVICE_MODE_WEB_SERVICE		// (5)
};

enum _VarioMode
{
	VARIO_MODE_INIT = 0,		// (0)
	VARIO_MODE_LANDING,			// (1)
	VARIO_MODE_FLYING,			// (2)
	VARIO_MODE_CIRCLING,		// (3)
};


////////////////////////////////////////////////////////////////////////////////////////
//
	
//
static PinSetting ePaperPins[] = 
{
	// CS
	{ SS, PIN_MODE_OUTPUT, PIN_ACTIVE_LOW, PIN_STATE_INACTIVE },
	// DC
	{ 33, PIN_MODE_OUTPUT, PIN_ACTIVE_LOW, PIN_STATE_INACTIVE },
	// RST
	{ 32, PIN_MODE_OUTPUT, PIN_ACTIVE_LOW, PIN_STATE_INACTIVE },
	// BUSY
	#if USE_GOOD_DISPLAY
	{ 39, PIN_MODE_INPUT, PIN_ACTIVE_HIGH, PIN_STATE_INACTIVE },
	#else
	{ 39, PIN_MODE_INPUT, PIN_ACTIVE_LOW, PIN_STATE_INACTIVE },
	#endif
};

static PinSetting powerPins[] =
{
	// PWR_PERIPH
	{ 19, PIN_MODE_OUTPUT, PIN_ACTIVE_HIGH, PIN_STATE_ACTIVE },
	// PWR_SOUND
	{ 27, PIN_MODE_OUTPUT, PIN_ACTIVE_HIGH, PIN_STATE_ACTIVE },
};

static PinSetting keybdPins[] =
{
	// KEY_UP
	{ 35, PIN_MODE_INPUT, PIN_ACTIVE_HIGH, PIN_STATE_ACTIVE },
	// KEY_DOWN
	{ 34, PIN_MODE_INPUT, PIN_ACTIVE_HIGH, PIN_STATE_ACTIVE },
	// KEY_SEL
	{  0, PIN_MODE_INPUT, PIN_ACTIVE_LOW, PIN_STATE_ACTIVE },
};


//

static Tone melodyVarioReady[] =
{
	{ -262, 1000 / 4 }, 
	{ -196, 1000 / 8 }, 
	{ -196, 1000 / 8 }, 
	{ -220, 1000 / 4 }, 
	{ -196, 1000 / 4 }, 
	{   0, 1000 / 4 }, 
	{ -247, 1000 / 4 }, 
	{ -262, 1000 / 4 },
	{   0, 1000 / 8 }, 
};
static Tone melodyTakeOff[] =
{
	{ -262, 1000 / 4 }, 
	{ -196, 1000 / 8 }, 
	{ -196, 1000 / 8 }, 
	{ -220, 1000 / 4 }, 
	{ -196, 1000 / 4 }, 
	{   0, 1000 / 4 }, 
	{ -247, 1000 / 4 }, 
	{ -262, 1000 / 4 },
	{   0, 1000 / 8 }, 
};

static Tone melodyLanding[] =
{
	{ -262, 1000 / 4 }, 
	{ -196, 1000 / 8 }, 
	{ -196, 1000 / 8 }, 
	{ -220, 1000 / 4 }, 
	{ -196, 1000 / 4 }, 
	{   0, 1000 / 4 }, 
	{ -247, 1000 / 4 }, 
	{ -262, 1000 / 4 },
	{   0, 1000 / 8 }, 
};


//
//
//

uint8_t deviceMode = DEVICE_MODE_UNDEF;
//uint8_t	varioMode; 		// sub-mode of vario-mode

RTC_DATA_ATTR uint32_t bootCount = 0;

uint32_t deviceTick;	// global tick-count
uint32_t modeTick;		// mode-specific tick-count

ScreenManager	scrnMan;
PopupTopMenu	popupTopMenu;
PopupWebService	popupWebService;


DeviceContext & context = __DeviceContext;


//
//
//

BluetoothSerialEx  	serialBluetooth;


//
//
//

#if USE_OLD_METHOD
SineGenerator toneGen;
TonePlayer tonePlayer(toneGen);
VarioBeeper varioBeeper(tonePlayer);
#else
Beeper beeper;
#endif

#if USE_DRIVER_TEMPLATE
#if USE_GOOD_DISPLAY
TVarioDisplayDriver<EPaper_GoodDisplay270> driver(ePaperPins);
#else
TVarioDisplayDriver<EPaper_Waveshare270> driver(ePaperPins);
#endif
#else
VarioDisplayDriver driver(ePaperPins);
#endif
VarioDisplay display(driver, context);

BatteryVoltage battery;
Keyboard keybd(keybdPins, sizeof(keybdPins) / sizeof(keybdPins[0]));

//
//
//

NmeaParserEx nmeaParser(Serial2, Serial);
VarioSentence varioNmea(VARIOMETER_DEFAULT_NMEA_SENTENCE);
VarioLogger logger;

//
//
//

#if USE_NORMAL_BTMAN // Normal Bluetooth manager
BluetoothMan btMan(serialBluetooth, nmeaParser, varioNmea);
#else // Logging raw NMEA sentence
BluetoothManEx btMan(serialBluetooth, nmeaParser, varioNmea);
#endif

//
//
//

CriticalSection cs;
Sensor_MS5611  baro(cs, Wire);
#if USE_KALMAN_VARIO
KalmanVario vario(baro);
#else
KalmanSkyDrop vario(baro);
#endif
VerticalSpeedCalculator varioCalculator;

//
//
//

AGL agl;


//
//
//

void readyFlight();
void startFlight();
void stopFlight();

void startCircling();
void startGliding();
void stopCircling();
void stopGliding();

void updateVarioState();
void updateFlightState();

void goDeepSleep();
void resetDevice();
void makeTopMenu();
void processKey(int key);
void startVario();
void loadPreferences();
void savePreferences();

void startWebService();
void toggleVarioSound();
void toggleBTService();
void toggleSimulation();

void setTimeZone(long offset, int daylight);


////////////////////////////////////////////////////////////////////////////////////////
//

void setup()
{
	// check wakeup reason
	switch (esp_sleep_get_wakeup_cause())
	{
	case ESP_SLEEP_WAKEUP_EXT0 :
	case ESP_SLEEP_WAKEUP_EXT1 : 
		deviceMode = DEVICE_MODE_WAKEUP;
		break;
	default :
		// if (reboot_for_preference)
		//   deviceMode = DEVICE_MODE_PREFERENCE
		// else
			deviceMode = DEVICE_MODE_VARIO;
		break;
	}

	// initialize serial(debug) & input key
	Serial.begin(115200);
	Serial.printf("Start MiniVario...\n\n");	
	//
	keybd.begin();

	// wakeup from deep-sleep
	//  --> check long key (sel)
	//  --> if not go deep-sleep again
	if (deviceMode == DEVICE_MODE_WAKEUP)
	{
		Serial.println("Wakeup from deepsleep: check long-ley input for delayed boot-up!");	
		uint32_t tick = millis();

		while (1)
		{
			keybd.update();

			if (keybd.getch() == KEY_SEL_LONG)
			{
				// wakeup confirmed!!
				break;
			}

			if ((millis() - tick) > BOOT_CHECKING_TIMOUT)
			{
				// deep-sleep again~
				Serial.println("go deep-sleep again~");
				delay(100);

				const int ext_wakeup_pin_1 = 34;
				const uint64_t ext_wakeup_pin_1_mask = 1ULL << ext_wakeup_pin_1;

				// Enabling EXT1 wakeup on pins GPIO34
				esp_sleep_enable_ext1_wakeup(ext_wakeup_pin_1_mask, ESP_EXT1_WAKEUP_ANY_HIGH);
				// Entering deep sleep
				esp_deep_sleep_start();

				while(1);
			}
		}

		deviceMode = DEVICE_MODE_VARIO;
	}

	// power on peripherals : default is power on
	initPins(powerPins, sizeof(powerPins) / sizeof(powerPins[0]));
	delay(100);

	// check sd-card & ready for use
	SD_CARD.begin();

	if (SD_CARD.valid())
	{
		FirmwareUpdater fu;

		if (fu.checkUpdate())
		{
			//
			fu.performUpdate(display);
			//
			ESP.restart();
		}		
		// else go down
	}
	else
	{
		Serial.printf("SD_CARD is invalid!!\n");
	}

	// load last device-context
	SPIFFS.begin();

	loadPreferences();
	setTimeZone(__DeviceContext.logger.timezone * -3600, 0);
	
	//
	TaskWatchdog::begin(TASK_TIMEOUT_S);
	TaskWatchdog::add(NULL);

	Serial2.begin(9600);
	Wire.begin();	
	display.begin(deviceMode == DEVICE_MODE_WAKEUP);
	beeper.begin();
	btMan.begin();
//	battery.begin();
//	vario.begin();

	// start right now or ...
	if (deviceMode == DEVICE_MODE_VARIO)
		startVario();

	//
	context.volume.vario = context.volume.varioDefault;
	context.volume.effect = context.volume.effectDefault;

	beeper.setMelody(NOTE_C4, 600, 60, 2, context.volume.effect, PLAY_PREEMPTIVE);
	deviceTick = millis();
}

void loop()
{
	//
	TaskWatchdog::reset();

	// check key-input
	keybd.update();
	
	// beeper update function is executed in task proc
	// beep beep beep!

	if (deviceMode == DEVICE_MODE_WAKEUP)
	{
		if ((millis() - deviceTick) > 10000)
		{
			goDeepSleep();
			while(1);
		}

		if (keybd.getch() == KEY_SEL)
			startVario();

		return;
	}

	if (vario.available())
	{
		//
		context.varioState.speedVertActive = vario.getVelocity();
		varioCalculator.add(context.varioState.speedVertActive);

//		context.varioState.speedVertLazy = context.varioState.speedVertLazy + (context.varioState.speedVertActive - context.varioState.speedVertLazy) * context.varioSetting.dampingFactor;
		context.varioState.speedVertLazy = varioCalculator.mVertSpeedAVG2; // 2s average
		context.varioState.altitudeBaro = vario.getAltitude();
		context.varioState.altitudeCalibrated = vario.getCalibratedAltitude();
		context.varioState.pressure = vario.getPressure();
		context.varioState.temperature = vario.getTemperature();

		//context.updateVarioHistory();
		context.varioState.speedVertSumCount = (context.varioState.speedVertSumCount + 1) % DEF_FREQUENCY;
		if (context.varioState.speedVertSumCount == 0)
		{
			context.varioState.speedVertHistory[context.varioState.speedVertNext] = varioCalculator.mVertSpeedAVG2; // 2s average
			context.varioState.speedVertNext = (context.varioState.speedVertNext + 1) % MAX_VARIO_HISTORY;
		}

		beeper.setVelocity(context.varioState.speedVertActive, context.volume.vario);

		//
		{
			//if (vario.getVelocity() < STABLE_SINKING_THRESHOLD || STABLE_CLIMBING_THRESHOLD < vario.getVelocity())
			if (context.varioState.speedVertLazy < STABLE_SINKING_THRESHOLD || STABLE_CLIMBING_THRESHOLD < context.varioState.speedVertLazy)
				deviceTick = millis(); // reset tick because it's not quiet.
			
			// if (commandReceiveFlag)
			// {
			// 	deviceTick =xx millis(); // reset tick because it's not quiet.
			// 	commandReceiveFlag = 0;
			// }
			
			if ((context.threshold.autoShutdownVario) && ((millis() - deviceTick) > context.threshold.autoShutdownVario))
				goDeepSleep();
		}			

		// update vario sentence periodically
		if (varioNmea.checkInterval())
			varioNmea.begin(vario.getAltitude(), vario.getVelocity(), vario.getTemperature(), vario.getPressure(), battery.getVoltage());
		
		//
		vario.flush();
	}
	
	// read & parse gps sentence
	nmeaParser.update();

	// update GPS fixed status
	context.deviceState.statusGPS = nmeaParser.isFixed() ? 1 : 0;

	// update vario state, if gps data is available
	if (nmeaParser.isDataReady())
	{
		updateVarioState();

		if (deviceMode == DEVICE_MODE_VARIO)
		{
			readyFlight();
		}
		else if (deviceMode == DEVICE_MODE_VARIO_AND_GPS)
		{
			if (context.flightState.flightMode == FMODE_READY)
			{
				if (nmeaParser.getSpeed() > context.logger.takeoffSpeed) // FLIGHT_START_MIN_SPEED)
				{
					startFlight();
				}
			}
			else
			{
				updateFlightState();

				if (nmeaParser.getSpeed() < context.logger.landingSpeed) // FLIGHT_START_MIN_SPEED)
				{
					if ((millis() - modeTick) > context.logger.landingTimeout) // FLIGHT_LANDING_THRESHOLD)
					{
						stopFlight();
					}
				}
				else
				{
					// reset modeTick
					modeTick = millis();
				}
				
				deviceTick = millis();
			}
		}

		nmeaParser.resetDataReady();
	}			
	
	#if _BLOCKED_ 
	// I wish it would be unfixed temporary. So I didn't reset mode. Wait unitil it is fixed
	if (deviceMode == DEVICE_MODE_VARIO_AND_GPS && !nmeaParser.isFixed())
	{
		
		if (context.flightState.flightMode != FMODE_READY)
			stopFlight();

		deviceMode = DEVICE_MODE_VARIO;
	}
	#endif

	// check logging state
	if (logger.isLogging() && nmeaParser.availableIGC())
	{
		// nmeaParser parses GPS sentence and converts it to IGC sentence
		
		//static unsigned long tick = millis();
		//static int index = 0;
		
		//if ((millis()-tick) > time_interval)
		{
			//
			float altitude = vario.getAltitude(); // getCalibratedAltitude or getAltitude
			logger.updateBaroAltitude(altitude);

			while (nmeaParser.availableIGC())
				logger.write(nmeaParser.readIGC());
		}
	}

	// send any prepared sentence to BT
	btMan.update();	

	//
	if (battery.update())
	{
		context.deviceState.batteryPower = battery.getVoltage();

		//if (context.deviceState.batteryPower < context.threshold.lowBattery)
		//{
		//	go shutdown
		//}
	}

	//
	int key = keybd.getch();
	if (key >= 0)
		processKey(key);

	//
	//WebService.update();
}

void readyFlight()
{
	// do position calibration
	vario.calibrateAltitude(nmeaParser.getAltitude());
	vario.calculateSeaLevel(nmeaParser.getAltitude());

	//
	struct timeval now = { nmeaParser.getDateTime(), 0 };
	//now.tv_sec +=  (__DeviceContext.logger.timezone * 60 * 60); // GMT(UTC+00) --> Local time
	settimeofday(&now, NULL);

	// play ready melody~~~
	//beeper.setMelody(&melodyVarioReady[0], sizeof(melodyVarioReady) / sizeof(melodyVarioReady[0]), 1, context.volume.effect/*, PLAY_PREEMPTIVE*/);
	beeper.setMelody(NOTE_C4, 400, 50, 3, context.volume.effect, PLAY_PREEMPTIVE);
	
	// now ready to fly~~~
	deviceMode = DEVICE_MODE_VARIO_AND_GPS;

	context.flightState.flightMode = FMODE_READY;
}

void startFlight()
{
	// trun on source if auto is set
	if (context.volume.autoTurnOn)
		context.volume.effect = context.volume.vario = 100;
	
	// play take-off melody
	//beeper.setMelody(&melodyTakeOff[0], sizeof(melodyTakeOff) / sizeof(melodyTakeOff[0]), 1, context.volume.effect/*, PLAY_PREEMPTIVE*/);
	beeper.setMelody(NOTE_C4, 1000, 80, 1, context.volume.effect, PLAY_PREEMPTIVE);

	//
	if (context.deviceDefault.enableNmeaLogging)
		btMan.startLogging(nmeaParser.getDateTime());
	
	// start logging & change mode
	if (context.logger.enable && logger.begin(nmeaParser.getDateTime()))
		context.deviceState.statusSDCard = 2;

	//
	context.varioSetting.altitudeRef1 = context.varioState.altitudeGPS;

	context.resetFlightState();
	context.resetFlightStats();

	context.flightState.takeOffTime = nmeaParser.getDateTime();
	context.flightState.takeOffPos.lat = context.varioState.latitude;
	context.flightState.takeOffPos.lon = context.varioState.longitude;
	context.flightState.takeOffPos.alt = context.varioState.altitudeGPS;
	context.flightState.bearingTakeoff = -1;
	context.flightState.flightMode = FMODE_FLYING;
	context.flightState.frontPoint = context.flightState.rearPoint = 0;

	context.flightStats.altitudeMax = context.flightStats.altitudeMin = context.varioState.altitudeGPS;

	// set mode-tick
	modeTick = millis();

	//
	//display.attachScreen(scrnMan.getActiveScreen());
	scrnMan.showActiveScreen(display);
}

void updateVarioState()
{
	context.varioState.latitudeLast = context.varioState.latitude;
	context.varioState.longitudeLast = context.varioState.longitude;
	context.varioState.headingLast = context.varioState.heading;

	context.varioState.latitude = nmeaParser.getLatitude();
	context.varioState.longitude = nmeaParser.getLongitude();
	context.varioState.speedGround = nmeaParser.getSpeed();
	context.varioState.heading = nmeaParser.getHeading();	
	context.varioState.timeCurrent = nmeaParser.getDateTime();
	context.varioState.altitudeGPS = nmeaParser.getAltitude();
	context.varioState.altitudeGround = agl.getGroundLevel(context.varioState.latitude, context.varioState.longitude);
	context.varioState.altitudeAGL = context.varioState.altitudeGPS - context.varioState.altitudeGround;
	context.varioState.altitudeRef1 = context.varioState.altitudeGPS - context.varioSetting.altitudeRef1;
	context.varioState.altitudeRef2 = context.varioState.altitudeGPS - context.varioSetting.altitudeRef2;
	context.varioState.altitudeRef3 = context.varioState.altitudeGPS - context.varioSetting.altitudeRef3;
}

void updateFlightState()
{
	// update flight time
	context.flightState.flightTime = nmeaParser.getDateTime() - context.flightState.takeOffTime;
	// update bearing & distance from takeoff
	context.flightState.bearingTakeoff = GET_BEARING(context.varioState.latitude, context.varioState.longitude, 
			context.flightState.takeOffPos.lat, context.flightState.takeOffPos.lon);
	context.flightState.distTakeoff = GET_DISTANCE(context.varioState.latitude, context.varioState.longitude, 
			context.flightState.takeOffPos.lat, context.flightState.takeOffPos.lon);
	// and update total flight distance
	context.flightState.distFlight += GET_DISTANCE(context.varioState.latitude, context.varioState.longitude, 
			context.varioState.latitudeLast, context.varioState.longitudeLast);
	// add new track point & calculate relative distance
	context.updateTrackHistory(context.varioState.latitude, context.varioState.longitude, context.varioState.speedVertLazy);

	// update flight statistics
	context.flightStats.altitudeMax = _MAX(context.flightStats.altitudeMax, context.varioState.altitudeGPS);
	context.flightStats.altitudeMin = _MIN(context.flightStats.altitudeMin, context.varioState.altitudeGPS);

	context.flightStats.varioMax = _MAX(context.flightStats.varioMax, context.varioState.speedVertLazy);
	context.flightStats.varioMin = _MIN(context.flightStats.varioMin, context.varioState.speedVertLazy);
	

	// check circling
	int16_t deltaHeading = context.varioState.heading - context.varioState.headingLast;

	if (deltaHeading > 180)
		deltaHeading = deltaHeading - 360;
	if (deltaHeading < -180)
		deltaHeading = deltaHeading + 360;

	//context.flightState.deltaHeading_AVG += (int16_t)((deltaHeading - context.flightState.deltaHeading_AVG) * DAMPING_FACTOR_DELTA_HEADING);
	context.flightState.deltaHeading_AVG = deltaHeading;
	context.flightState.deltaHeading_SUM += context.flightState.deltaHeading_AVG;
	context.flightState.deltaHeading_SUM = _CLAMP(context.flightState.deltaHeading_SUM, -450, 450); // one and a half turns

	if (abs(context.flightState.deltaHeading_AVG) < THRESHOLD_CIRCLING_HEADING)	
		context.flightState.glidingCount = _MIN(MAX_GLIDING_COUNT, context.flightState.glidingCount + 1);
	else
		context.flightState.glidingCount = _MAX(MIN_GLIDING_COUNT, context.flightState.glidingCount - 1);

	switch (context.flightState.flightMode)
	{
	case FMODE_FLYING :
		if (abs(context.flightState.deltaHeading_SUM) > 360)
		{
			startCircling();
		}
		else if (context.flightState.glidingCount > GLIDING_START_COUNT)
		{
			startGliding();
		}
		break;

	case FMODE_CIRCLING :
		// update time & gain
		context.flightState.circlingTime = nmeaParser.getDateTime() - context.flightState.circlingStartTime;
		context.flightState.circlingGain = nmeaParser.getAltitude() - context.flightState.circlingStartPos.alt;

		// checking exit
		if (context.flightState.glidingCount > CIRCLING_EXIT_COUNT)
		{
			// CIRCLING --> FLYING(NORMAL)
			stopCircling();
		}
		break;

	case FMODE_GLIDING :
		// update gliding ratio(L/D)
		{
			float dist = GET_DISTANCE(context.flightState.glidingStartPos.lat, context.flightState.glidingStartPos.lon,
				context.varioState.latitude, context.varioState.longitude);

			if (dist > 100)
			{
				if (context.flightState.glidingStartPos.alt > context.varioState.altitudeGPS)
				{
					float diff = context.flightState.glidingStartPos.alt - context.varioState.altitudeGPS;
					context.flightState.glideRatio = dist / diff;
				}
				else
				{
					context.flightState.glideRatio = 0; // INF
				}
			}
		}

		// checking exit
		if (context.flightState.glidingCount < GLIDING_EXIT_COUNT)
		{
			// GLIDING --> FLYING(NORMAL)
			stopGliding();
		}
		break;
	}
}

void stopFlight()
{
	//
	context.flightState.flightMode = FMODE_READY;

	//
	context.flightState.bearingTakeoff = -1;
	
	// play landing melody
	//beeper.setMelody(&melodyLanding[0], sizeof(melodyLanding) / sizeof(melodyLanding[0]), 1, context.volume.effect/*, PLAY_PREEMPTIVE*/);
	beeper.setMelody(NOTE_C3, 1000, 80, 1, context.volume.effect, PLAY_PREEMPTIVE);

	//
	btMan.stopLogging();
	
	// stop logging & change mode
	if (logger.isLogging())
	{
		logger.end(nmeaParser.getDateTime());
		context.deviceState.statusSDCard = 1;
	}

	//
	//display.attachScreen(scrnMan.getStatisticScreen());	
	scrnMan.showStatisticScreen(display);

	// restore volume if it is turn on start flying
	if (context.volume.autoTurnOn)
	{
		context.volume.vario = context.volume.varioDefault;
		context.volume.effect = context.volume.effectDefault;
	}
}

void startCircling()
{
	// start of circling
	context.flightState.flightMode = FMODE_CIRCLING;

	// save circling state
	context.flightState.circlingStartTime = nmeaParser.getDateTime();
	context.flightState.circlingStartPos.lon = nmeaParser.getLongitude();
	context.flightState.circlingStartPos.lat = nmeaParser.getLatitude();
	context.flightState.circlingStartPos.alt = nmeaParser.getAltitude();
	context.flightState.circlingIncline = -1;

	context.flightState.circlingTime = 0;
	context.flightState.circlingGain = 0;

	context.flightState.glidingCount = 0;

	//
	//display.attachScreen(scrnMan.getCirclingScreen());
	scrnMan.showCirclingScreen(display);
}

void startGliding()
{
	// start of circling
	context.flightState.flightMode = FMODE_GLIDING;

	//
	context.flightState.glidingStartPos.lon = nmeaParser.getLongitude();
	context.flightState.glidingStartPos.lat = nmeaParser.getLatitude();
	context.flightState.glidingStartPos.alt = nmeaParser.getAltitude();

	context.flightState.glideRatio = -1;
}

void stopCircling()
{
	// now normal flying
	context.flightState.flightMode = FMODE_FLYING;

	// update flight-statistics : thermaling count, max-gain
	if (context.flightState.circlingGain > 10 && context.flightState.circlingTime > 0)
	{
		context.flightStats.totalThermaling += 1;
		context.flightStats.thermalingMaxGain = _MAX(context.flightStats.thermalingMaxGain, context.flightState.circlingGain);
	}

	context.flightState.deltaHeading_AVG = 0;
	context.flightState.deltaHeading_SUM = 0;

	//
	//display.attachScreen(scrnMan.getActiveScreen());
	scrnMan.showActiveScreen(display);
}

void stopGliding()
{
	// now normal flying
	context.flightState.flightMode = FMODE_FLYING;

	//
	context.flightState.glideRatio = -1;
}
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

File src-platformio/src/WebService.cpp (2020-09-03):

// WebService.cpp
//

#include "DeviceContext.h"
#include "WebService.h"
#include <ArduinoJson.h>
#include "SdCard.h"


///////////////////////////////////////////////////////////////////////////////////
//

bool parseBoolean(String str)
{
    if (str == "true")
        return true;

    return false;
}

int parseInteger(String str)
{
    return atoi(str.c_str());
}

float parseFloat(String str)
{
    return atof(str.c_str());
}

String getDateString(time_t t)
{
    struct tm * _tm;
    _tm = gmtime(&t);

    char str[32]; // YYYY-MM-DD hh:mm:ssZ
    String date;
    
    sprintf(str, "%d-%d-%d %d:%d:%dZ", 
        _tm->tm_year + 1900, _tm->tm_mon + 1, _tm->tm_mday,
        _tm->tm_hour, _tm->tm_min, _tm->tm_sec);

    return String(str);
}


///////////////////////////////////////////////////////////////////////////////////
//

WebServiceClass  WebService;


///////////////////////////////////////////////////////////////////////////////////
// class WebServiceClass

WebServiceClass::WebServiceClass()
{
}

WebServiceClass::~WebServiceClass()
{
}

void WebServiceClass::start()
{
    DeviceContext & context = __DeviceContext;

    //
    WiFi.persistent(false);
    WiFi.mode(WIFI_AP);
    WiFi.softAPConfig(IPAddress(192, 168, 1, 1), IPAddress(192, 168, 1, 1), IPAddress(255, 255, 255, 0));
    WiFi.softAP(context.deviceDefault.wifiSSID, context.deviceDefault.wifiPassword);
    IPAddress myIP = WiFi.softAPIP();
    Serial.print("AP IP address: ");
    Serial.println(myIP);

    //
    WebServer::on("/Update/{}", HTTP_POST, onUpdateRequest);
    WebServer::on("/TrackLogs/list", HTTP_GET, onRequestTrackLogs);
    WebServer::on("/TrackLogs/{}", HTTP_GET, onDownloadTrackLog);
    WebServer::on("/TrackLogs/{}", HTTP_DELETE, onDeleteTrackLog);
    WebServer::onNotFound(onRequest);

    WebServer::begin(80);
}

void WebServiceClass::stop()
{
    WebServer::close();
    WiFi.softAPdisconnect(true);
}

void WebServiceClass::update()
{
    WebServer::handleClient();
}


const char * WebServiceClass::getContentType(String filename)
{
    if (filename.endsWith(".htm") || filename.endsWith(".html"))
        return "text/html";

    if (filename.endsWith(".css"))
        return "text/css";

    if (filename.endsWith(".js"))
        return "application/javascript";

    if (filename.endsWith(".json"))
        return "application/json";

    if (filename.endsWith(".png"))
        return "image/png";

    if (filename.endsWith(".gif"))
        return "image/gif";

    if (filename.endsWith(".jpg"))
        return "image/jpeg";

    if (filename.endsWith(".ico"))
        return "image/x-icon";

    //if (filename.endsWith(".xml"))
    //    return "text/xml";

    //if (filename.endsWith(".zip"))
    //    return "application/x-zip";

    if (filename.endsWith(".gz"))
        return "application/x-gzip";

    //if (filename.endsWith(".pdf"))
    //    return "application/x-pdf";

    if (filename.endsWith(".igc"))
        return "application/octet-stream";

    return "text/plain";
}

bool WebServiceClass::checkExist(fs::FS & fs, String path)
{
    bool exist = false;

    File file = fs.open(path, "r");
    if (! file.isDirectory())
        exist = true;
    file.close();

    return exist;
}

bool WebServiceClass::handleFileRead(fs::FS & fs, String path)
{
    Serial.print("handleFileRead: ");
    Serial.println(path);
    if (path.endsWith("/"))
        path += "index.html";

    String contentType = getContentType(path);
    Serial.println("  contentType: " + contentType);
    String path_gz = path + ".gz";

    //if (checkExist(fs, path_gz) || checkExist(fs, path))
    if (fs.exists(path_gz) || fs.exists(path))
    {
        //if (checkExist(fs, path_gz))
        if (fs.exists(path_gz))
            path = path + ".gz";

        Serial.printf("  Open: %s\n", path.c_str());
        File file = fs.open(path, "r");
        if (file)
        {
            WebService.streamFile(file, contentType);
            file.close();

            return true;
        }
        
        Serial.println("  File open failed!");    
        WebService.send(400, "text/plain", "File Open Failed");
    }
    else
    {
        Serial.println("  File not exist!");
        WebService.send(404, "text/plain", "File Not Found");
    }

    return false;
}


void WebServiceClass::onUpdateRequest()
{
    //
    String target = "/" + WebService.pathArg(0);
    if (! SPIFFS.exists(target))
    {
        Serial.printf("File Not Exist: %s\n", target);

        WebService.send(404, "text/plain", "File Not Found");
    }
    else
    {
        //
        const size_t capacity = JSON_OBJECT_SIZE(29) + 1024;
        DynamicJsonDocument doc(capacity);

        // read
        {
            File file = SPIFFS.open(target, FILE_READ);
            if (file)
            {
                deserializeJson(doc, file);
                file.close();
            }
        }

        // update
        for (int i = 0; i < WebService.args(); i++)
        {
            Serial.printf("%s: %s\n", WebService.argName(i).c_str(), WebService.arg(i).c_str());

            String name = WebService.argName(i);
            String value = WebService.arg(i);
            JsonVariant var = doc[name];

            if (! var.isNull())
            {
                if (var.is<bool>())
                    doc[name] = parseBoolean(value);
                else if (var.is<int>())
                    doc[name] = parseInteger(value);
                else if (var.is<float>())
                    doc[name] = parseFloat(value);
                else
                    doc[name] = value;
            }
            else
            {
                doc[name] = value;
            }
        }

        // save
        {
            File file = SPIFFS.open(target, FILE_WRITE);
            size_t size = 0;

            if (file)
            {
                size = serializeJson(doc, file);
                file.close();

                Serial.printf("Serialize %d bytes\n", size);
            }

            if (size != 0)
            {
                Serial.printf("Update Success.\n");

                WebService.send(200, "text/plain", "OK");
            }
            else
            {
                Serial.printf("Update Failed!\n");
                WebService.send(400, "text/plain", "File Write Failed");
            }
        }
    }
}
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

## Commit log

2019-03-10 add ref : arduino-esp32, esp-idf
2019-03-12 add schematic
    [MiniVario_Full.sch]
2019-03-13 add datasheets update pads
    [MiniVario_Full.sch]
2019-03-15 new case model
    [Case.FCStd]
2019-03-16 update pads
    [MiniVario_Full.sch]
2019-03-17 case design
    [Case.FCStd, MiniVario_Full.sch]
2019-03-19 update case
    [Case.FCStd]
2019-03-19 update pads file add gerber file
    [drl001.drl]
2019-03-21 update 3d-model
    [Case.FCStd]
2019-03-25 update & add 3d-model
    [Case-Small Button.FCStd, Case.FCStd]
2019-03-30 update 3d-model & pads
    [Case.FCStd, MiniVario_Full.sch]
2019-04-03 update Timer test --> use rtos
2019-04-04 add pressure/vario test
2019-04-05 temperature example
2019-04-06 add datasheets change pressure osr: 4096 samples
2019-04-11 - battery power acquisition : TBD - implement Task class - simple deep sleep : TBD
2019-04-11 apply Keyboard to main & some bug fixed
    [main.ino]
2019-04-12 redefine DeviceContext
2019-04-14 update 3d-model : space for GPS module
    [Case-Alt.FCStd]
2019-04-15 update/add 3d-model
    [Case-Alt-RoundBtn.FCStd, Case-Alt.FCStd]
2019-04-15 try beep-sound bug --> not sure what is problem!
    [SineWave.ino, main.ino]
2019-04-19 [Known Bug] - tone generator never stop - display nan when bt is connected
    [BTSerial.ino, KalmanVario.cpp, Pressure.ino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]
2019-04-19 add missing file: BluetoothCallback, HardReset
    [BluetoothCallback.cpp]
2019-04-19 Bug Fixed: removed some noise
    [main.ino]
2019-05-03 test new kalman filter
2019-05-06 revert to KalmanVario change default dampling-factor
    [main.ino]
2019-05-09 add new page add some widget content bug fix: bearing(takeoff) is revised from heading.
    [main.ino]
2019-05-14 logging gps & vario sentence revise circling algorithm add ground-level widget
2019-06-06 change vario update frequency -> 100Hz conflict(?) with bluetooth serial Task -> 50Hz is experimental frequency
2019-06-09 remove timer from pressure acquisition method
2019-07-03 implement track history
2019-07-12 send simulation data(nmea) to device
2019-07-12 add track window
2019-07-13 draw track with heading
2019-07-15 auto screen switch -> switch screen when it is begin circling or it is terminate flight. logging nmea data only if its option is on
2019-07-15 ESP32 Sketch Data Upload refs: https://randomnerdtutorials.com/install-esp32-filesystem-uploader-arduino-ide/
2019-07-15 prevent deep-sleep when it's flight
    [main.ino]
2019-07-16 add submodules: AsyncTCP, ESPAsyncWebServer add sample web pages
2019-07-19 preferences sample pages
2019-07-24 working.... de-serialize json
2019-07-28 working... webservice on the device
2019-07-29 webservice: change toggle switch design webservice popup (cond) set/reset device context by json sound on/off key assigned
    [WebService.cpp, main.ino]
2019-07-29 modified to use context values. bug fixed that save context incorrectly. removed unused data files new context variable: landingSpeed
    [main.ino]
2019-07-31 webservice: track logs management
2019-07-31 esp32 boards configuration --> support MiniVario partion 2x6.5MB app, 3.6MB SPIFFS
2019-08-01 bug fixed: - reversed track drawing - L/D calculation
    [main.ino]
2019-08-01 change beep method webservice: sort track logs
2019-08-02 bug fixed: - changed beeper task procedure - corrected a wrong use of duty
    improved digital i/o
    [main.ino]
2019-08-17 change beep duty rate change default configuration mini_vario partition csv
    [mini_vario.csv]
2020-02-24 pcb layout
2020-02-25 update schematic pdf & add bom
    [MiniVario_Full.sch]
2020-07-20 rev2 tbd
    [MiniVario_Full.sch, MiniVario_Rev2.sch]
2020-07-20 add document: GY-91, IPEX connector
2020-07-22 update case : carve spacer
    [Case-Alt-RoundBtn.FCStd]
2020-08-02 pcb(rev_2) working
    [MiniVario_Rev2.sch]
2020-09-01 fixed nmea parsing bug : working
    [main.ino]
2020-09-02 fixed nmea parsing bug
    [GpsSimulatorDlg.cpp, main.ino]
2020-09-03 fixed nmea buffer management error
    [GpsSimulatorDlg.cpp, WebService.cpp, main.ino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]
2023-09-04 support platformio-build
    [mini_vario.csv]
2023-09-07 change tone-table
    [ToneTable.xlsx]
